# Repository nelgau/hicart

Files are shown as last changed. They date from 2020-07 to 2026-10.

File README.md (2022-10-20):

# Home Invader 64

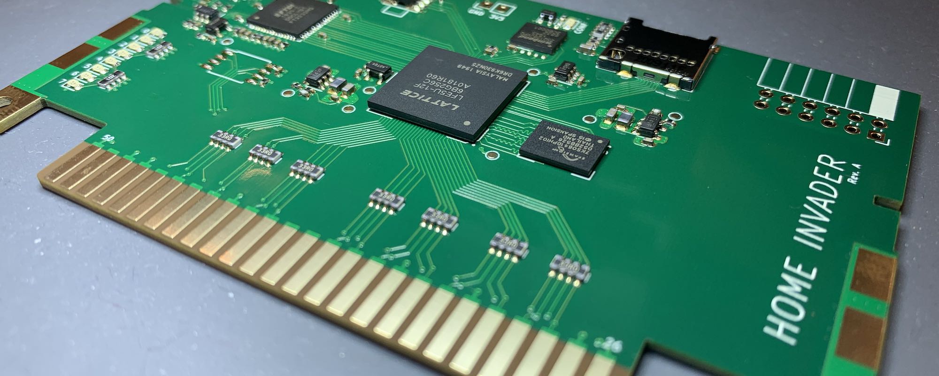
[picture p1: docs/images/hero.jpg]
Hero


This is a present for an old friend!

## Prerequisites

Get these taps:

    $ brew tap nelgau/fpga
    $ brew tap riscv-software-src/riscv

Install the following packages:

    $ brew install --HEAD yosys
    $ brew install --HEAD nelgau/fpga/nextpnr-ecp5
    $ brew install --HEAD nelgau/fpga/ecpprog
    $ brew install riscv-software-src/riscv/riscv-tools
    $ brew install icarus-verilog

Note: Building `nextpnr-ecp5` takes approximately 11 minutes on an M1 MacBook Pro.

Build a recent Python with shared object support (for cocotb) using pyenv:

    $ PYTHON_CONFIGURE_OPTS="--enable-shared" pyenv install 3.10.6

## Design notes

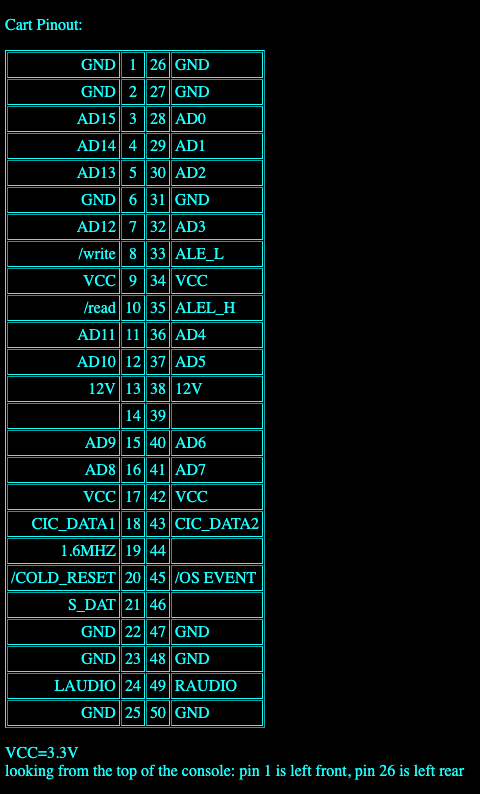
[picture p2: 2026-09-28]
docs/n64/N64 Cartridge Pinout (crazynation).png

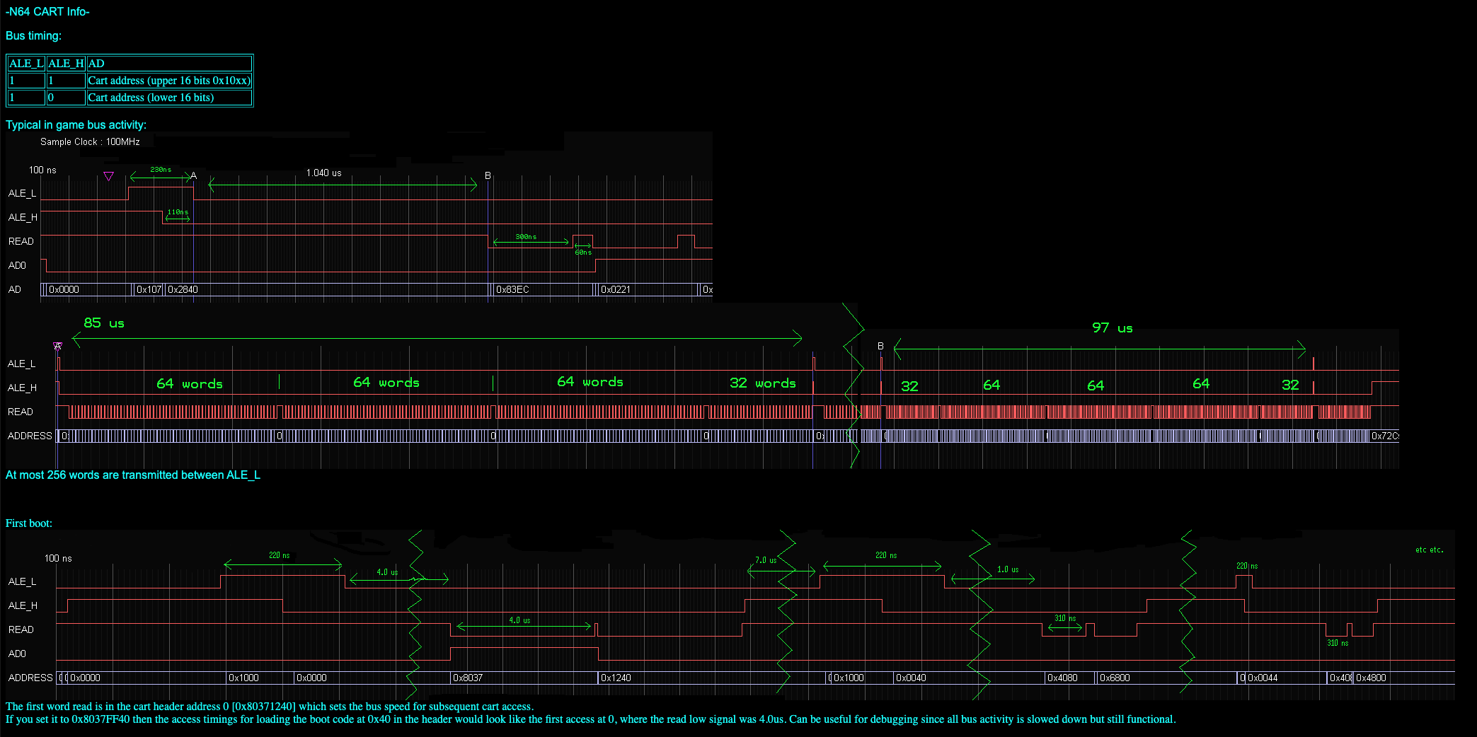
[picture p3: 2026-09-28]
docs/n64/N64 Cartridge Timings (crazynation).png

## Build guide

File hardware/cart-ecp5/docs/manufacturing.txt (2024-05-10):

**
*   JLCPCB 4-Layer Process
**

Deviations:

- Copper to hole clearance

    For BGA breakout, via hole to track
    Adjusted to 0.225mm, from 0.254mm (JLCPCB)

- Minimum text height

    For silkscreen labels throughout
    Adjusted to 0.75mm, from 1.0mm (JLCPCB)

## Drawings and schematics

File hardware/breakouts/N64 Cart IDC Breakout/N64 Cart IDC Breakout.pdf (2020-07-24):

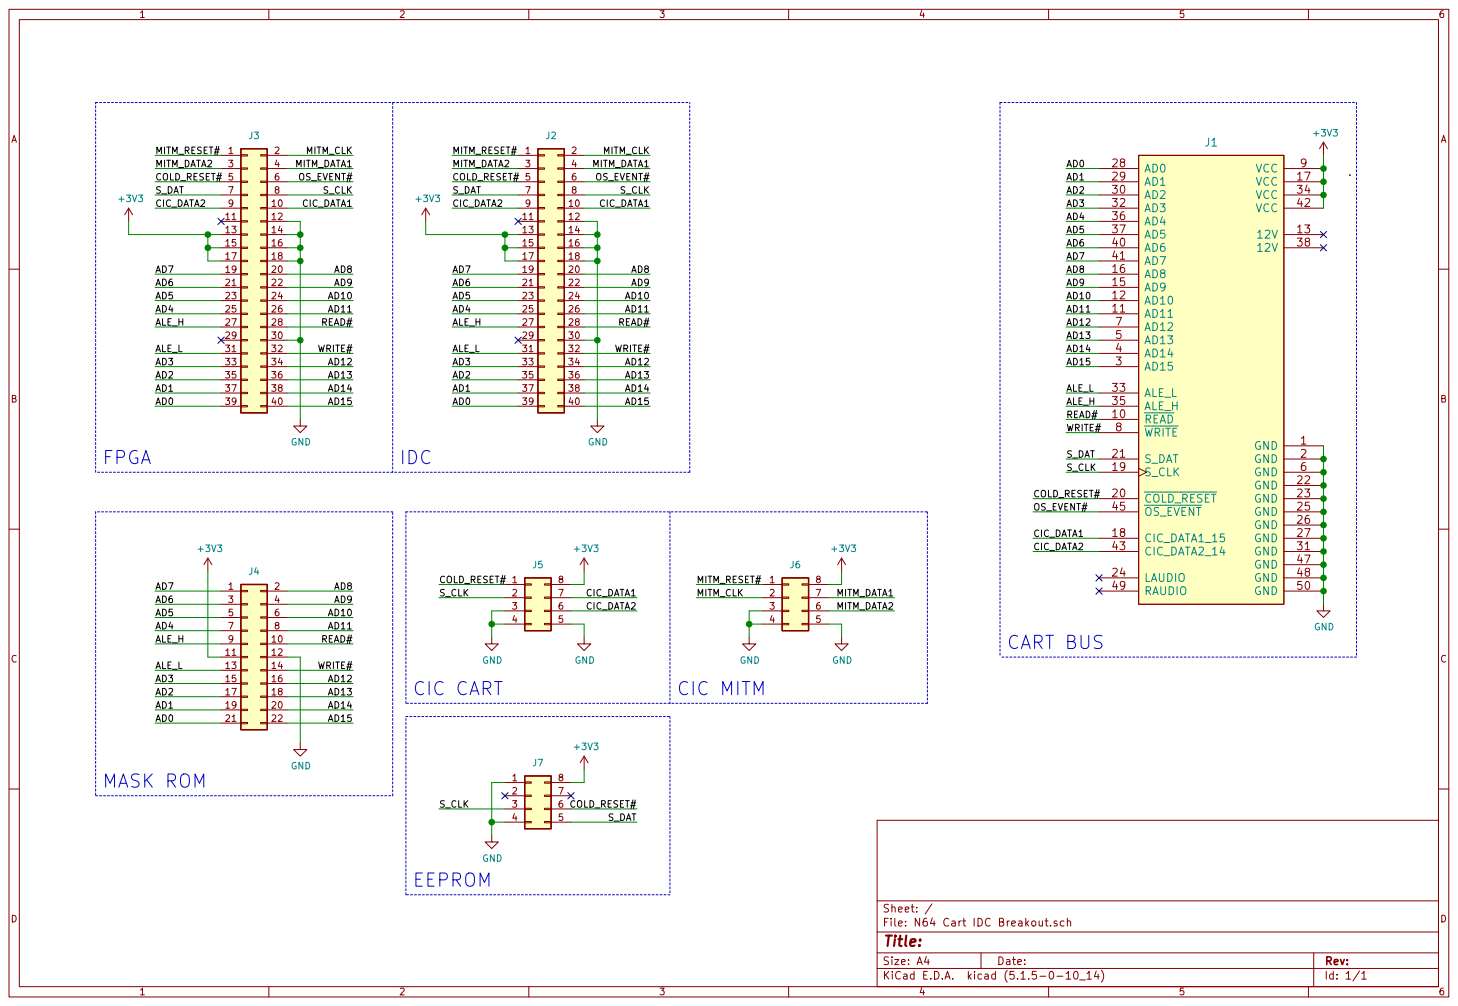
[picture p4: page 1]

Id: 1/1 Title: File: N64 Cart IDC Breakout.sch Sheet: /

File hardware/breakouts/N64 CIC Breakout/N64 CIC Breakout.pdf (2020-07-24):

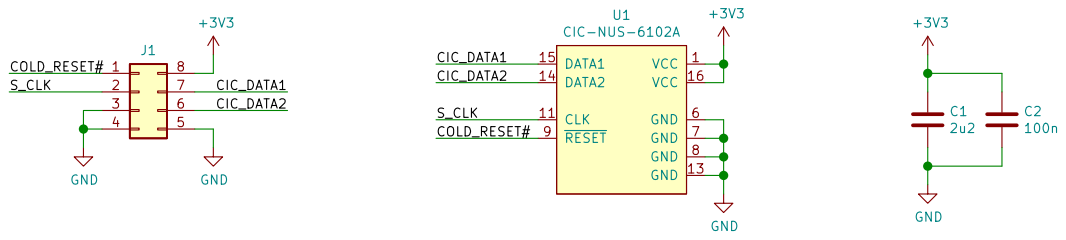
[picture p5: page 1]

Id: 1/1 Title: File: N64 CIC Breakout.sch Sheet: /

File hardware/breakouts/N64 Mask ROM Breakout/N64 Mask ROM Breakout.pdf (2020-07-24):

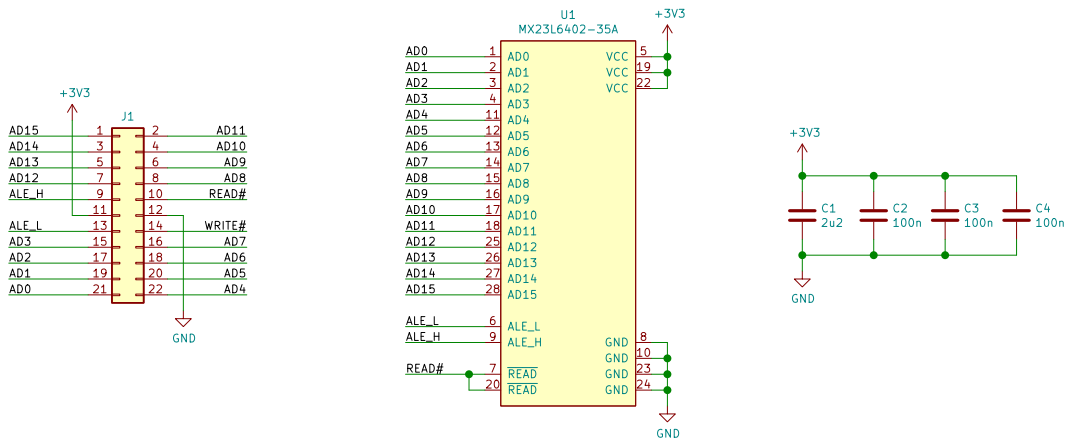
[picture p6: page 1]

Id: 1/1 Title: File: N64 Mask ROM Breakout.sch Sheet: /

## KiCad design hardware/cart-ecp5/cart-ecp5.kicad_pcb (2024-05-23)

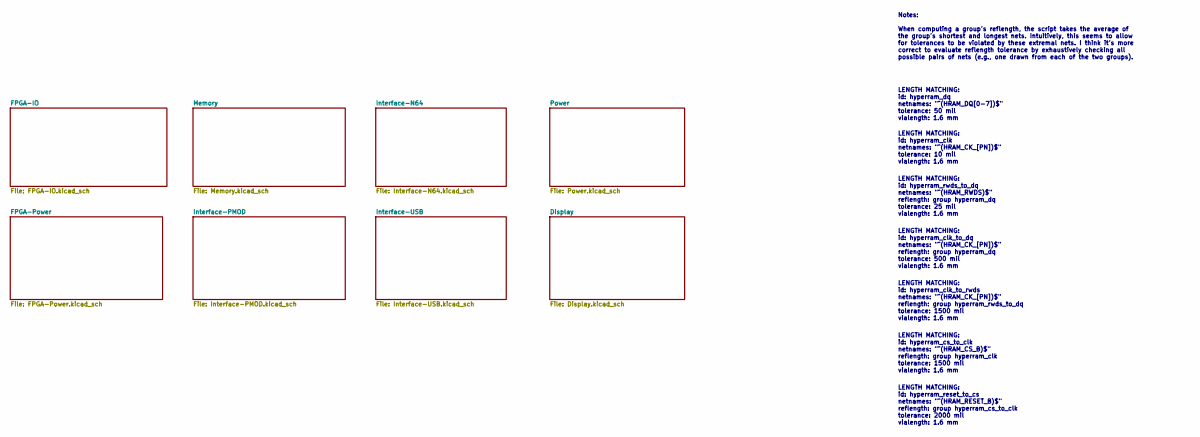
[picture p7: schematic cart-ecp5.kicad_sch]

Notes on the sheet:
LENGTH MATCHING: id: hyperram_reset_to_cs netnames: "^(HRAM_RESET_B)$" reflength: group hyperram_cs_to_clk tolerance: 2000 mil vialength: 1.6 mm
LENGTH MATCHING: id: hyperram_clk_to_dq netnames: "^(HRAM_CK_[PN])$" reflength: group hyperram_dq tolerance: 500 mil vialength: 1.6 mm
LENGTH MATCHING: id: hyperram_clk netnames: "^(HRAM_CK_[PN])$" tolerance: 10 mil vialength: 1.6 mm
LENGTH MATCHING: id: hyperram_dq netnames: "^(HRAM_DQ[0-7])$" tolerance: 50 mil vialength: 1.6 mm
LENGTH MATCHING: id: hyperram_clk_to_rwds netnames: "^(HRAM_CK_[PN])$" reflength: group hyperram_rwds_to_dq tolerance: 1500 mil vialength: 1.6 mm
LENGTH MATCHING: id: hyperram_cs_to_clk netnames: "^(HRAM_CS_B)$" reflength: group hyperram_clk tolerance: 1500 mil vialength: 1.6 mm
LENGTH MATCHING: id: hyperram_rwds_to_dq netnames: "^(HRAM_RWDS)$" reflength: group hyperram_dq tolerance: 25 mil vialength: 1.6 mm
Notes: When computing a group's reflength, the script takes the average of the group's shortest and longest nets. Intuitively, this seems to allow for tolerances to be violated by these extremal nets. I think it's more correct to evaluate reflength tolerance by exhaustively checking all possible pa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

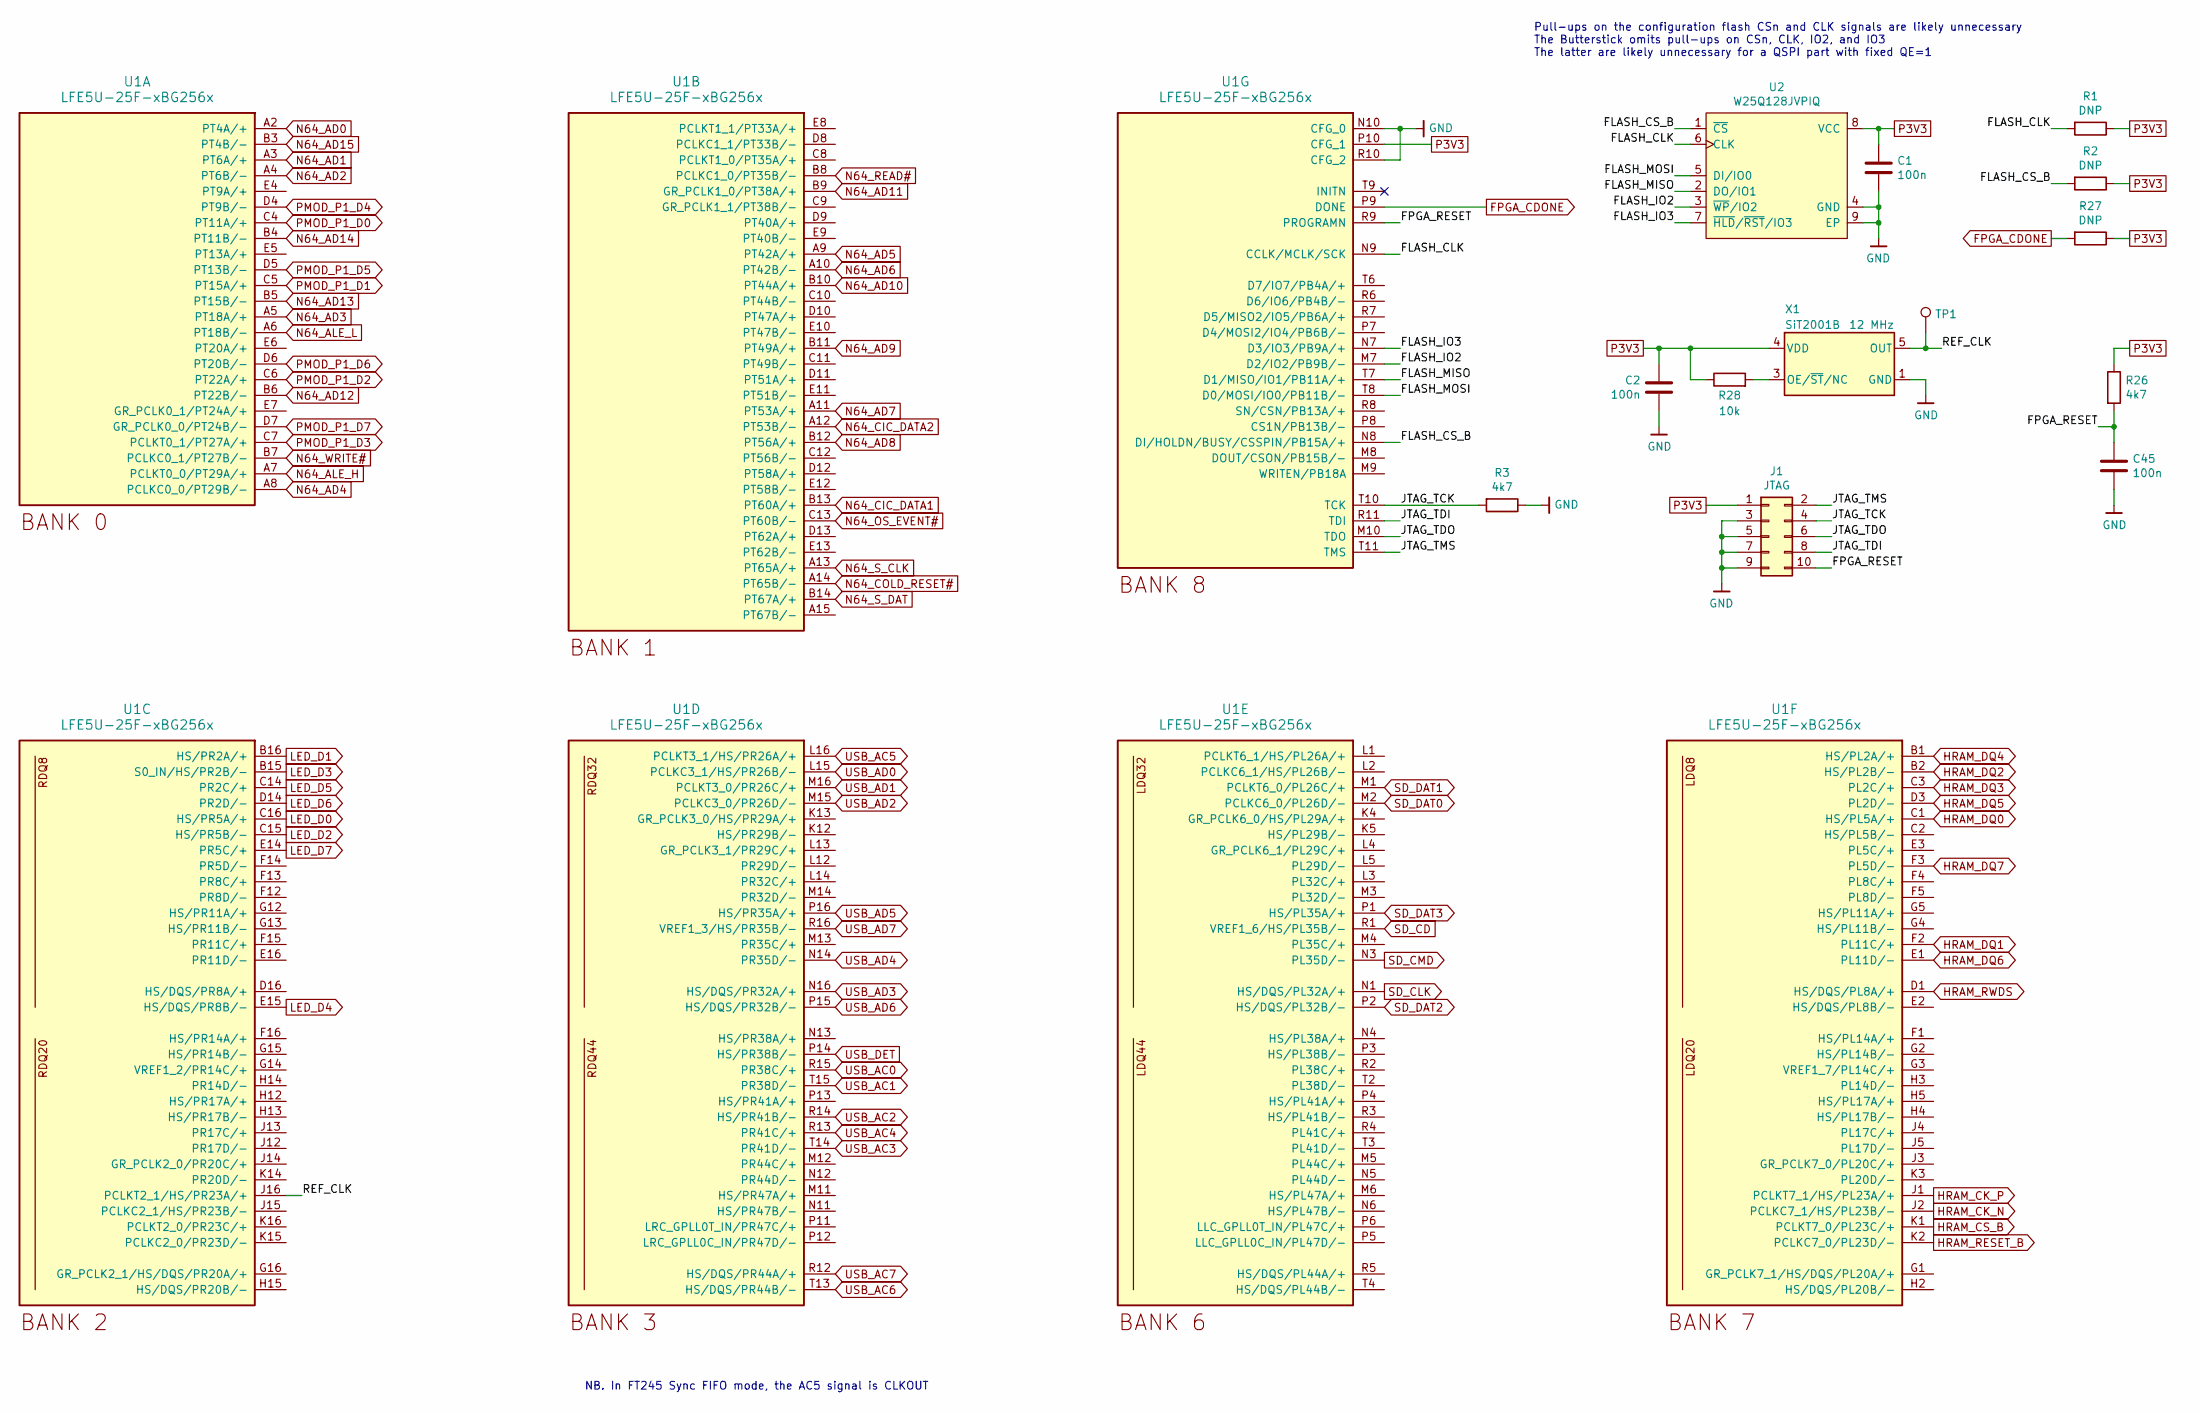
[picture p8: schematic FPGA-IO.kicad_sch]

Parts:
C1, C2, C45: 100n; C_0402_1005Metric; MPN CL05B104KO5NNNC
J1: JTAG; Samtec_FTSH-105-XX-X-DV-Mating; MPN FTSH-105-01-L-DV-K
R1, R2, R27: DNP; R_0402_1005Metric
R3, R26: 4k7; R_0402_1005Metric; MPN RC0402FR-074K7L
R28: 10k; R_0402_1005Metric; MPN RC0402FR-0710KL
TP1: TestPoint; TestPoint_Pad_D1.0mm
U1: LFE5U-25F-xBG256x; LFE5U-25F_BGA-256_14.0x14.0mm_Layout16x16_P0.8mm_Pad0.35mm; MPN LFE5U-25F-xBG256x
U2: W25Q128JVPIQ; WSON-8-1EP_6x5mm_P1.27mm_EP3.4x4mm; MPN W25Q128JVPIQ
X1: SiT2001B; SOT-23-5; MPN SiT2001BI-S2-33E-12.000000G

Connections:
/FPGA-IO/FLASH_CLK: R1.2, U1.N9 (CCLK/MCLK/SCK), U2.6 (CLK)
/FPGA-IO/FLASH_CS_B: R2.2, U1.N8 (DI/HOLDN/BUSY/CSSPIN/PB15A/+), U2.1 (~CS)
/FPGA-IO/FLASH_IO2: U1.M7 (D2/IO2/PB9B/-), U2.3 (~WP/IO2)
/FPGA-IO/FLASH_IO3: U1.N7 (D3/IO3/PB9A/+), U2.7 (~HLD/~RST/IO3)
/FPGA-IO/FLASH_MISO: U1.T7 (D1/MISO/IO1/PB11A/+), U2.2 (DO/IO1)
/FPGA-IO/FLASH_MOSI: U1.T8 (D0/MOSI/IO0/PB11B/-), U2.5 (DI/IO0)
/FPGA-IO/FPGA_RESET: C45.1, J1.10, R26.2, U1.R9 (PROGRAMN)
/FPGA-IO/JTAG_TCK: J1.4, R3.2, U1.T10 (TCK)
/FPGA-IO/JTAG_TDI: J1.8, U1.R11 (TDI)
/FPGA-IO/JTAG_TDO: J1.6, U1.M10 (TDO)
/FPGA-IO/JTAG_TMS: J1.2, U1.T11 (TMS)
/FPGA-IO/REF_CLK: TP1.1, U1.J16 (PCLKT2_1/HS/PR23A/+), X1.5 (OUT)
FPGA_CDONE: R27.2, U1.P9 (DONE); also elsewhere on the board
GND: C1.2, C2.2, C45.2, J1.3, J1.5, J1.7, J1.9, R3.1, U1.N10 (CFG_0), U1.R10 (CFG_2), U2.4 (GND), U2.9 (EP), X1.1 (GND); also elsewhere on the board
HRAM_CK_N: U1.J2 (PCLKC7_1/HS/PL23B/-); also elsewhere on the board
HRAM_CK_P: U1.J1 (PCLKT7_1/HS/PL23A/+); also elsewhere on the board
HRAM_CS_B: U1.K1 (PCLKT7_0/PL23C/+); also elsewhere on the board
HRAM_DQ0: U1.C1 (HS/PL5A/+); also elsewhere on the board
HRAM_DQ1: U1.F2 (PL11C/+); also elsewhere on the board
HRAM_DQ2: U1.B2 (HS/PL2B/-); also elsewhere on the board
HRAM_DQ3: U1.C3 (PL2C/+); also elsewhere on the board
HRAM_DQ4: U1.B1 (HS/PL2A/+); also elsewhere on the board
HRAM_DQ5: U1.D3 (PL2D/-); also elsewhere on the board
HRAM_DQ6: U1.E1 (PL11D/-); also elsewhere on the board
HRAM_DQ7: U1.F3 (PL5D/-); also elsewhere on the board
HRAM_RESET_B: U1.K2 (PCLKC7_0/PL23D/-); also elsewhere on the board
HRAM_RWDS: U1.D1 (HS/DQS/PL8A/+); also elsewhere on the board
LED_D0: U1.C16 (HS/PR5A/+); also elsewhere on the board
LED_D1: U1.B16 (HS/PR2A/+); also elsewhere on the board
LED_D2: U1.C15 (HS/PR5B/-); also elsewhere on the board
LED_D3: U1.B15 (S0_IN/HS/PR2B/-); also elsewhere on the board
LED_D4: U1.E15 (HS/DQS/PR8B/-); also elsewhere on the board
LED_D5: U1.C14 (PR2C/+); also elsewhere on the board
LED_D6: U1.D14 (PR2D/-); also elsewhere on the board
LED_D7: U1.E14 (PR5C/+); also elsewhere on the board
N64_AD0: U1.A2 (PT4A/+); also elsewhere on the board
N64_AD1: U1.A3 (PT6A/+); also elsewhere on the board
N64_AD2: U1.A4 (PT6B/-); also elsewhere on the board
N64_AD3: U1.A5 (PT18A/+); also elsewhere on the board
N64_AD4: U1.A8 (PCLKC0_0/PT29B/-); also elsewhere on the board
N64_AD5: U1.A9 (PT42A/+); also elsewhere on the board
N64_AD6: U1.A10 (PT42B/-); also elsewhere on the board
N64_AD7: U1.A11 (PT53A/+); also elsewhere on the board
N64_AD8: U1.B12 (PT56A/+); also elsewhere on the board
N64_AD9: U1.B11 (PT49A/+); also elsewhere on the board
N64_AD10: U1.B10 (PT44A/+); also elsewhere on the board
N64_AD11: U1.B9 (GR_PCLK1_0/PT38A/+); also elsewhere on the board
N64_AD12: U1.B6 (PT22B/-); also elsewhere on the board
N64_AD13: U1.B5 (PT15B/-); also elsewhere on the board
N64_AD14: U1.B4 (PT11B/-); also elsewhere on the board
N64_AD15: U1.B3 (PT4B/-); also elsewhere on the board
N64_ALE_H: U1.A7 (PCLKT0_0/PT29A/+); also elsewhere on the board
N64_ALE_L: U1.A6 (PT18B/-); also elsewhere on the board
N64_CIC_DATA1: U1.B13 (PT60A/+); also elsewhere on the board
N64_CIC_DATA2: U1.A12 (PT53B/-); also elsewhere on the board
N64_COLD_RESET#: U1.A14 (PT65B/-); also elsewhere on the board
N64_OS_EVENT#: U1.C13 (PT60B/-); also elsewhere on the board
N64_READ#: U1.B8 (PCLKC1_0/PT35B/-); also elsewhere on the board
N64_S_CLK: U1.A13 (PT65A/+); also elsewhere on the board
N64_S_DAT: U1.B14 (PT67A/+); also elsewhere on the board
N64_WRITE#: U1.B7 (PCLKC0_1/PT27B/-); also elsewhere on the board
unnamed: R28.2, X1.3 (OE/~ST/NC)
P3V3: C1.1, C2.1, J1.1, R1.1, R2.1, R26.1, R27.1, R28.1, U1.P10 (CFG_1), U2.8 (VCC), X1.4 (VDD); also elsewhere on the board
PMOD_P1_D0: U1.C4 (PT11A/+); also elsewhere on the board
PMOD_P1_D1: U1.C5 (PT15A/+); also elsewhere on the board
PMOD_P1_D2: U1.C6 (PT22A/+); also elsewhere on the board
PMOD_P1_D3: U1.C7 (PCLKT0_1/PT27A/+); also elsewhere on the board
PMOD_P1_D4: U1.D4 (PT9B/-); also elsewhere on the board
PMOD_P1_D5: U1.D5 (PT13B/-); also elsewhere on the board
PMOD_P1_D6: U1.D6 (PT20B/-); also elsewhere on the board
PMOD_P1_D7: U1.D7 (GR_PCLK0_0/PT24B/-); also elsewhere on the board
SD_CD: U1.R1 (VREF1_6/HS/PL35B/-); also elsewhere on the board
SD_CLK: U1.N1 (HS/DQS/PL32A/+); also elsewhere on the board
SD_CMD: U1.N3 (PL35D/-); also elsewhere on the board
SD_DAT0: U1.M2 (PCLKC6_0/PL26D/-); also elsewhere on the board
SD_DAT1: U1.M1 (PCLKT6_0/PL26C/+); also elsewhere on the board
SD_DAT2: U1.P2 (HS/DQS/PL32B/-); also elsewhere on the board
SD_DAT3: U1.P1 (HS/PL35A/+); also elsewhere on the board
USB_AC0: U1.R15 (PR38C/+); also elsewhere on the board
USB_AC1: U1.T15 (PR38D/-); also elsewhere on the board
USB_AC2: U1.R14 (HS/PR41B/-); also elsewhere on the board
USB_AC3: U1.T14 (PR41D/-); also elsewhere on the board
USB_AC4: U1.R13 (PR41C/+); also elsewhere on the board
USB_AC5: U1.L16 (PCLKT3_1/HS/PR26A/+); also elsewhere on the board
USB_AC6: U1.T13 (HS/DQS/PR44B/-); also elsewhere on the board
USB_AC7: U1.R12 (HS/DQS/PR44A/+); also elsewhere on the board
USB_AD0: U1.L15 (PCLKC3_1/HS/PR26B/-); also elsewhere on the board
USB_AD1: U1.M16 (PCLKT3_0/PR26C/+); also elsewhere on the board
USB_AD2: U1.M15 (PCLKC3_0/PR26D/-); also elsewhere on the board
USB_AD3: U1.N16 (HS/DQS/PR32A/+); also elsewhere on the board
USB_AD4: U1.N14 (PR35D/-); also elsewhere on the board
USB_AD5: U1.P16 (HS/PR35A/+); also elsewhere on the board
USB_AD6: U1.P15 (HS/DQS/PR32B/-); also elsewhere on the board
USB_AD7: U1.R16 (VREF1_3/HS/PR35B/-); also elsewhere on the board
USB_DET: U1.P14 (HS/PR38B/-); also elsewhere on the board

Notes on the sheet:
NB. In FT245 Sync FIFO mode, the AC5 signal is CLKOUT
Pull-ups on the configuration flash CSn and CLK signals are likely unnecessary The Butterstick omits pull-ups on CSn, CLK, IO2, and IO3 The latter are likely unnecessary for a QSPI part with fixed QE=1

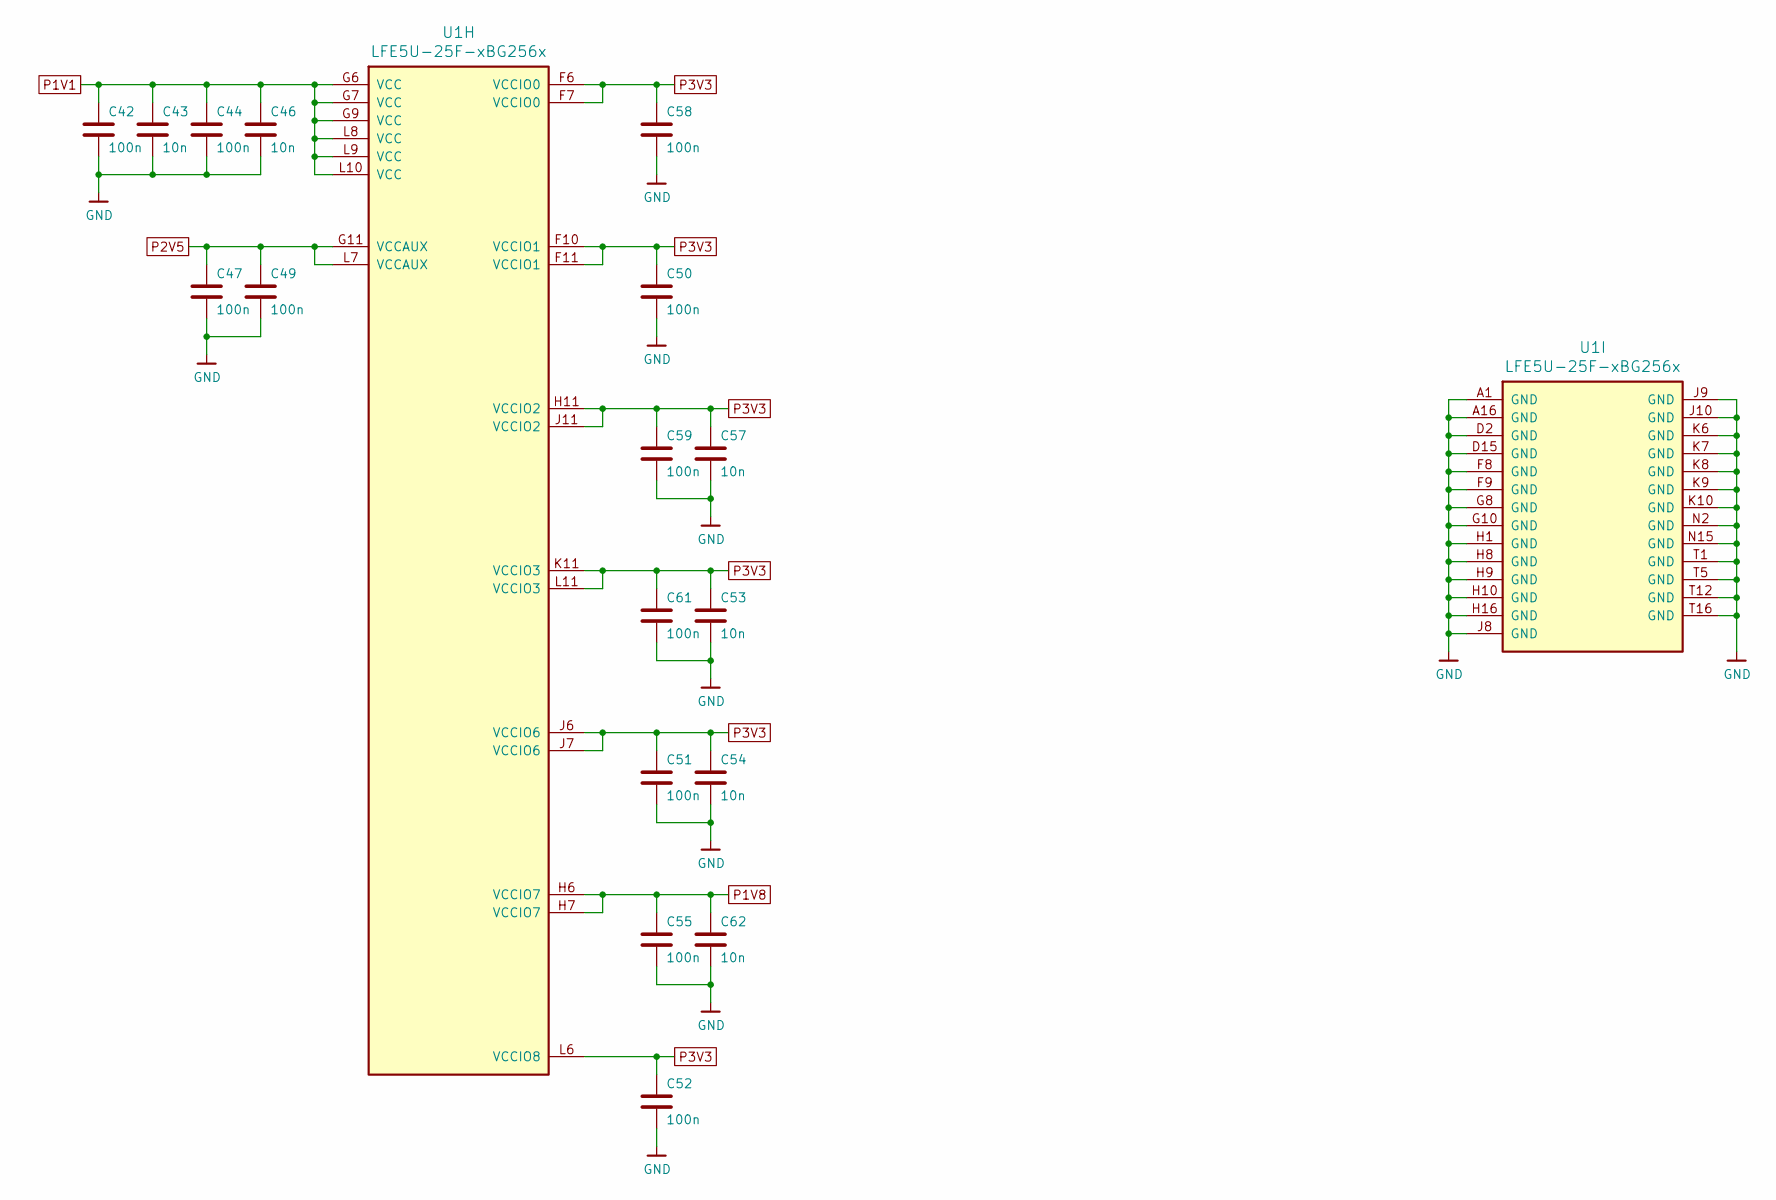
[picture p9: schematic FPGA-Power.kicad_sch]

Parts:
C42, C44, C47, C49, C50, C51, C52, C55, C58, C59, C61: 100n; C_0402_1005Metric; MPN CL05B104KO5NNNC
C43, C46, C53, C54, C57, C62: 10n; C_0402_1005Metric; MPN CL05B103KB5NNNC
U1: LFE5U-25F-xBG256x; LFE5U-25F_BGA-256_14.0x14.0mm_Layout16x16_P0.8mm_Pad0.35mm; MPN LFE5U-25F-xBG256x

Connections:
GND: C42.2, C43.2, C44.2, C46.2, C47.2, C49.2, C50.2, C51.2, C52.2, C53.2, C54.2, C55.2, C57.2, C58.2, C59.2, C61.2, C62.2, U1.A1 (GND), U1.A16 (GND), U1.D2 (GND), U1.D15 (GND), U1.F8 (GND), U1.F9 (GND), U1.G8 (GND), U1.G10 (GND), U1.H1 (GND), U1.H8 (GND), U1.H9 (GND), U1.H10 (GND), U1.H16 (GND), U1.J8 (GND), U1.J9 (GND), U1.J10 (GND), U1.K6 (GND), U1.K7 (GND), U1.K8 (GND), U1.K9 (GND), U1.K10 (GND), U1.N2 (GND), U1.N15 (GND), U1.T1 (GND), U1.T5 (GND), U1.T12 (GND), U1.T16 (GND); also elsewhere on the board
P1V1: C42.1, C43.1, C44.1, C46.1, U1.G6 (VCC), U1.G7 (VCC), U1.G9 (VCC), U1.L8 (VCC), U1.L9 (VCC), U1.L10 (VCC); also elsewhere on the board
P1V8: C55.1, C62.1, U1.H6 (VCCIO7), U1.H7 (VCCIO7); also elsewhere on the board
P2V5: C47.1, C49.1, U1.G11 (VCCAUX), U1.L7 (VCCAUX); also elsewhere on the board
P3V3: C50.1, C51.1, C52.1, C53.1, C54.1, C57.1, C58.1, C59.1, C61.1, U1.F6 (VCCIO0), U1.F7 (VCCIO0), U1.F10 (VCCIO1), U1.F11 (VCCIO1), U1.H11 (VCCIO2), U1.J6 (VCCIO6), U1.J7 (VCCIO6), U1.J11 (VCCIO2), U1.K11 (VCCIO3), U1.L6 (VCCIO8), U1.L11 (VCCIO3); also elsewhere on the board

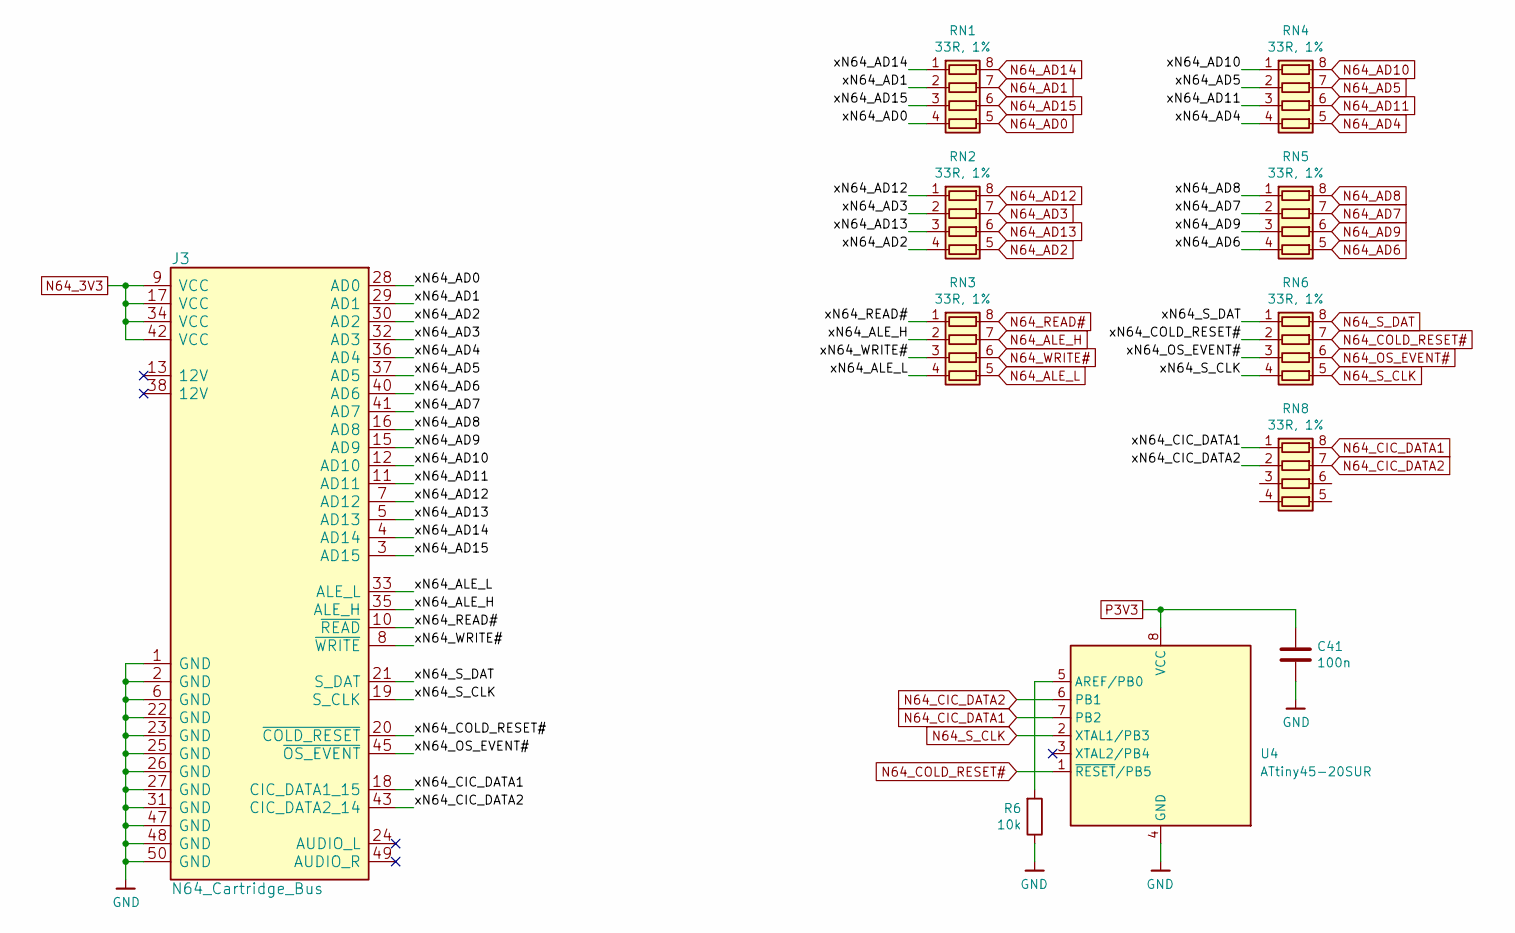
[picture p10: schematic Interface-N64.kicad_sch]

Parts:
C41: 100n; C_0402_1005Metric; MPN CL05B104KO5NNNC
J3: N64_Cartridge_Bus; N64_Cartridge_Edge
R6: 10k; R_0402_1005Metric; MPN RC0402FR-0710KL
RN1, RN2, RN3, RN4, RN5, RN6, RN8: 33R, 1%; R_Array_Convex_4x0603; MPN YC164-FR-0733RL
U4: ATtiny45-20SUR; SOIC-8W_5.3x5.3mm_P1.27mm; MPN ATTINY45-20SUR

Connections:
/Interface-N64/xN64_AD0: J3.28 (AD0), RN1.4 (R4.1)
/Interface-N64/xN64_AD1: J3.29 (AD1), RN1.2 (R2.1)
/Interface-N64/xN64_AD2: J3.30 (AD2), RN2.4 (R4.1)
/Interface-N64/xN64_AD3: J3.32 (AD3), RN2.2 (R2.1)
/Interface-N64/xN64_AD4: J3.36 (AD4), RN4.4 (R4.1)
/Interface-N64/xN64_AD5: J3.37 (AD5), RN4.2 (R2.1)
/Interface-N64/xN64_AD6: J3.40 (AD6), RN5.4 (R4.1)
/Interface-N64/xN64_AD7: J3.41 (AD7), RN5.2 (R2.1)
/Interface-N64/xN64_AD8: J3.16 (AD8), RN5.1 (R1.1)
/Interface-N64/xN64_AD9: J3.15 (AD9), RN5.3 (R3.1)
/Interface-N64/xN64_AD10: J3.12 (AD10), RN4.1 (R1.1)
/Interface-N64/xN64_AD11: J3.11 (AD11), RN4.3 (R3.1)
/Interface-N64/xN64_AD12: J3.7 (AD12), RN2.1 (R1.1)
/Interface-N64/xN64_AD13: J3.5 (AD13), RN2.3 (R3.1)
/Interface-N64/xN64_AD14: J3.4 (AD14), RN1.1 (R1.1)
/Interface-N64/xN64_AD15: J3.3 (AD15), RN1.3 (R3.1)
/Interface-N64/xN64_ALE_H: J3.35 (ALE_H), RN3.2 (R2.1)
/Interface-N64/xN64_ALE_L: J3.33 (ALE_L), RN3.4 (R4.1)
/Interface-N64/xN64_CIC_DATA1: J3.18 (CIC_DATA1_15), RN8.1 (R1.1)
/Interface-N64/xN64_CIC_DATA2: J3.43 (CIC_DATA2_14), RN8.2 (R2.1)
/Interface-N64/xN64_COLD_RESET#: J3.20 (~COLD_RESET), RN6.2 (R2.1)
/Interface-N64/xN64_OS_EVENT#: J3.45 (~OS_EVENT), RN6.3 (R3.1)
/Interface-N64/xN64_READ#: J3.10 (~READ), RN3.1 (R1.1)
/Interface-N64/xN64_S_CLK: J3.19 (S_CLK), RN6.4 (R4.1)
/Interface-N64/xN64_S_DAT: J3.21 (S_DAT), RN6.1 (R1.1)
/Interface-N64/xN64_WRITE#: J3.8 (~WRITE), RN3.3 (R3.1)
GND: C41.2, J3.1 (GND), J3.2 (GND), J3.6 (GND), J3.22 (GND), J3.23 (GND), J3.25 (GND), J3.26 (GND), J3.27 (GND), J3.31 (GND), J3.47 (GND), J3.48 (GND), J3.50 (GND), R6.1, U4.4 (GND); also elsewhere on the board
N64_3V3: J3.9 (VCC), J3.17 (VCC), J3.34 (VCC), J3.42 (VCC); also elsewhere on the board
N64_AD0: RN1.5 (R4.2); also elsewhere on the board
N64_AD1: RN1.7 (R2.2); also elsewhere on the board
N64_AD2: RN2.5 (R4.2); also elsewhere on the board
N64_AD3: RN2.7 (R2.2); also elsewhere on the board
N64_AD4: RN4.5 (R4.2); also elsewhere on the board
N64_AD5: RN4.7 (R2.2); also elsewhere on the board
N64_AD6: RN5.5 (R4.2); also elsewhere on the board
N64_AD7: RN5.7 (R2.2); also elsewhere on the board
N64_AD8: RN5.8 (R1.2); also elsewhere on the board
N64_AD9: RN5.6 (R3.2); also elsewhere on the board
N64_AD10: RN4.8 (R1.2); also elsewhere on the board
N64_AD11: RN4.6 (R3.2); also elsewhere on the board
N64_AD12: RN2.8 (R1.2); also elsewhere on the board
N64_AD13: RN2.6 (R3.2); also elsewhere on the board
N64_AD14: RN1.8 (R1.2); also elsewhere on the board
N64_AD15: RN1.6 (R3.2); also elsewhere on the board
N64_ALE_H: RN3.7 (R2.2); also elsewhere on the board
N64_ALE_L: RN3.5 (R4.2); also elsewhere on the board
N64_CIC_DATA1: RN8.8 (R1.2), U4.7 (PB2); also elsewhere on the board
N64_CIC_DATA2: RN8.7 (R2.2), U4.6 (PB1); also elsewhere on the board
N64_COLD_RESET#: RN6.7 (R2.2), U4.1 (~RESET/PB5); also elsewhere on the board
N64_OS_EVENT#: RN6.6 (R3.2); also elsewhere on the board
N64_READ#: RN3.8 (R1.2); also elsewhere on the board
N64_S_CLK: RN6.5 (R4.2), U4.2 (XTAL1/PB3); also elsewhere on the board
N64_S_DAT: RN6.8 (R1.2); also elsewhere on the board
N64_WRITE#: RN3.6 (R3.2); also elsewhere on the board
unnamed: R6.2, U4.5 (AREF/PB0)
P3V3: C41.1, U4.8 (VCC); also elsewhere on the board

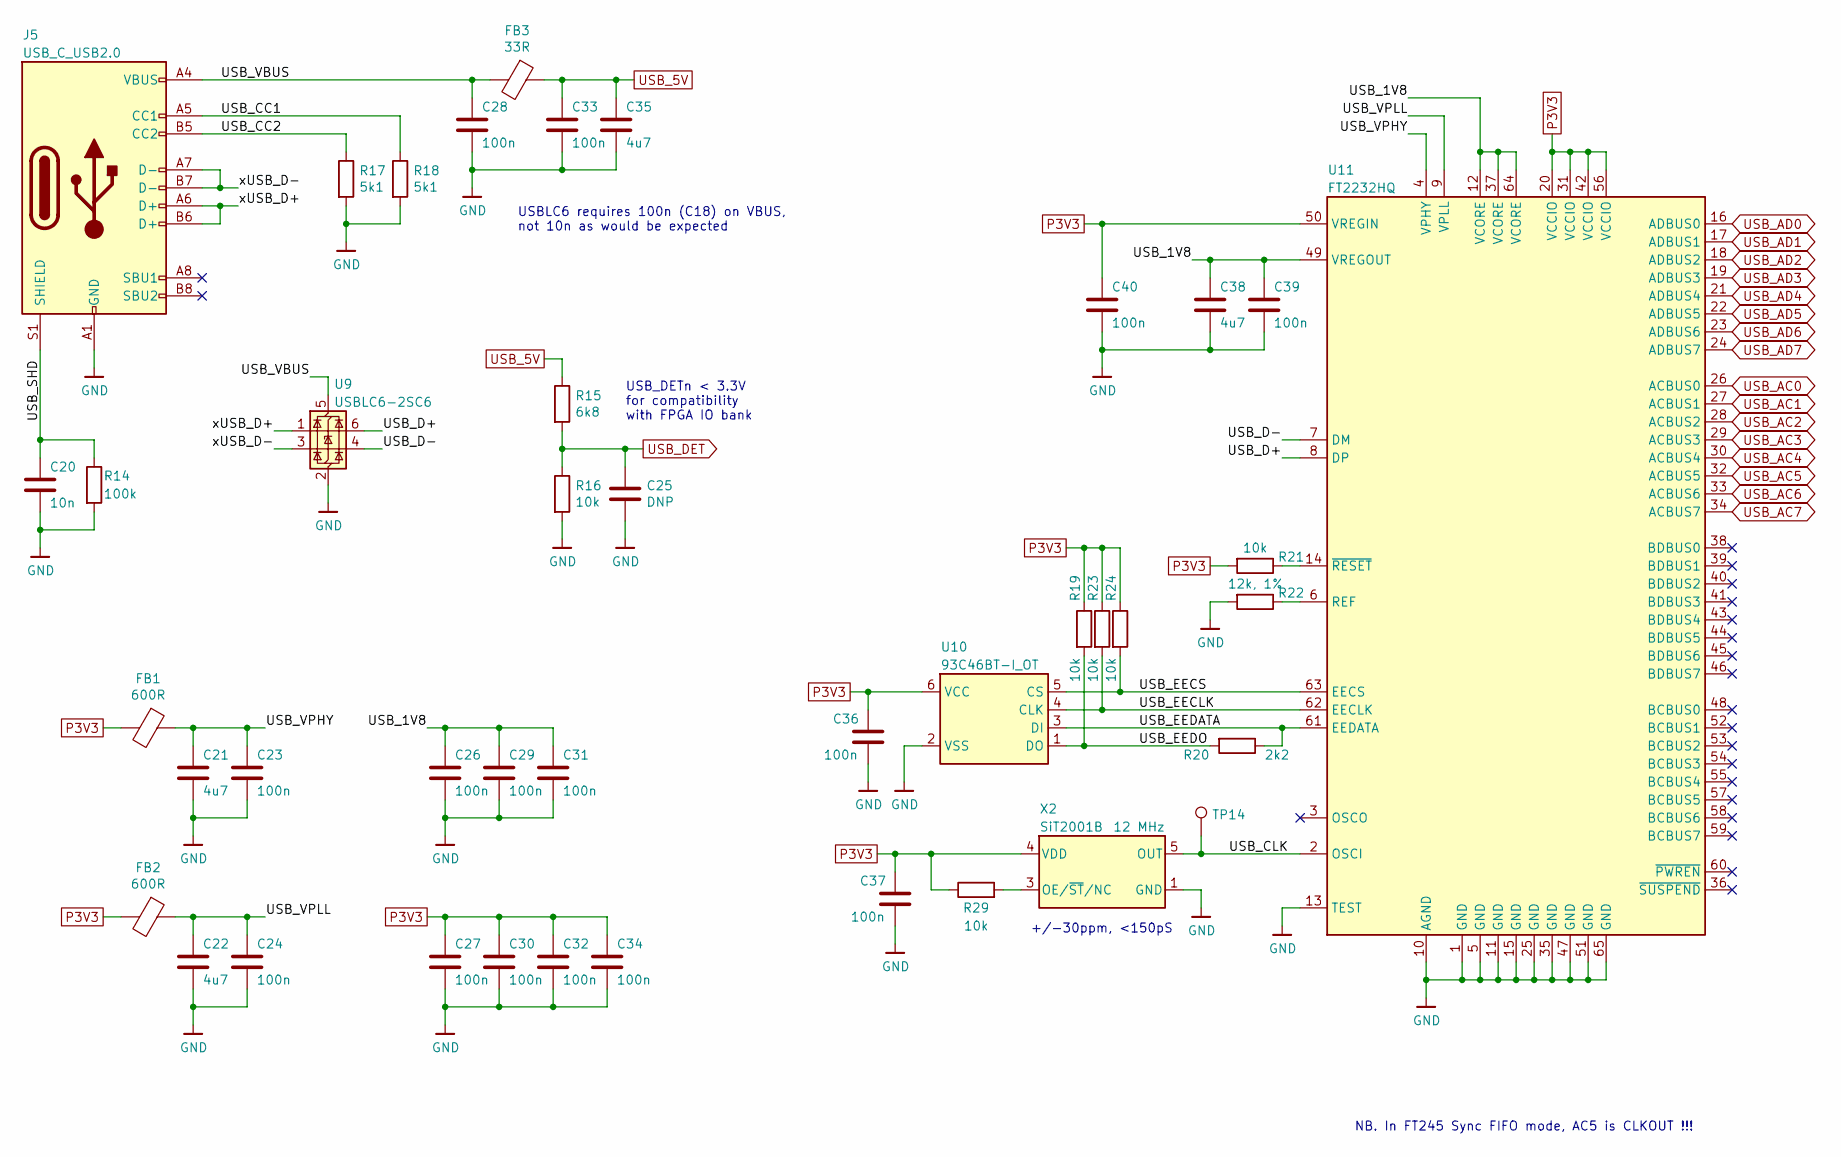
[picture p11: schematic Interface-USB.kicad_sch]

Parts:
C20: 10n; C_0402_1005Metric; MPN CL05B103KB5NNNC
C21, C22, C35, C38: 4u7; C_0402_1005Metric; MPN CL05A475KP5NRNC
C23, C24, C26, C27, C28, C29, C30, C31, C32, C33, C34, C36, C37, C39, C40: 100n; C_0402_1005Metric; MPN CL05B104KO5NNNC
C25: DNP; C_0402_1005Metric
FB1, FB2: 600R; L_0402_1005Metric; MPN BLM15PX601SN1D
FB3: 33R; L_0402_1005Metric; MPN MPZ1005S330HT000
J5: USB_C_USB2.0; USB_C_Receptacle_HRO_TYPE-C-31-M-12; MPN TYPE-C-31-M-12
R14: 100k; R_0402_1005Metric; MPN RC0402FR-07100KL
R15: 6k8; R_0402_1005Metric; MPN RC0402FR-076K8L
R16, R19, R21, R23, R24, R29: 10k; R_0402_1005Metric; MPN RC0402FR-0710KL
R17, R18: 5k1; R_0402_1005Metric; MPN RC0402FR-075K1L
R20: 2k2; R_0402_1005Metric; MPN RC0402FR-072K2L
R22: 12k, 1%; R_0402_1005Metric; MPN RC0402FR-0712KL
TP14: TestPoint; TestPoint_Pad_D1.0mm
U9: USBLC6-2SC6; SOT-23-6; MPN USBLC6-2SC6
U10: 93C46BT-I_OT; SOT-23-6; MPN 93C46BT-I/OT
U11: FT2232HQ; QFN-64-1EP_9x9mm_P0.5mm_EP4.35x4.35mm; MPN FT2232HQ
X2: SiT2001B; SOT-23-5; MPN SiT2001BI-S2-33E-12.000000G

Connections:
/Interface-USB/USB_1V8: C26.1, C29.1, C31.1, C38.1, C39.1, U11.12 (VCORE), U11.37 (VCORE), U11.49 (VREGOUT), U11.64 (VCORE)
/Interface-USB/USB_CC1: J5.A5 (CC1), R18.1
/Interface-USB/USB_CC2: J5.B5 (CC2), R17.1
/Interface-USB/USB_CLK: TP14.1, U11.2 (OSCI), X2.5 (OUT)
/Interface-USB/USB_D+: U9.6 (I/O1), U11.8 (DP)
/Interface-USB/USB_D-: U9.4 (I/O2), U11.7 (DM)
/Interface-USB/USB_EECLK: R23.2, U10.4 (CLK), U11.62 (EECLK)
/Interface-USB/USB_EECS: R24.2, U10.5 (CS), U11.63 (EECS)
/Interface-USB/USB_EEDATA: R20.1, U10.3 (DI), U11.61 (EEDATA)
/Interface-USB/USB_EEDO: R19.2, R20.2, U10.1 (DO)
/Interface-USB/USB_SHD: C20.1, J5.S1 (SHIELD), R14.1
/Interface-USB/USB_VBUS: C28.1, FB3.2, J5.A4 (VBUS), J5.A9 (VBUS), J5.B4 (VBUS), J5.B9 (VBUS), U9.5 (VBUS)
/Interface-USB/USB_VPHY: C21.1, C23.1, FB1.1, U11.4 (VPHY)
/Interface-USB/USB_VPLL: C22.1, C24.1, FB2.1, U11.9 (VPLL)
/Interface-USB/xUSB_D+: J5.A6 (D+), J5.B6 (D+), U9.1 (I/O1)
/Interface-USB/xUSB_D-: J5.A7 (D-), J5.B7 (D-), U9.3 (I/O2)
GND: C20.2, C21.2, C22.2, C23.2, C24.2, C25.2, C26.2, C27.2, C28.2, C29.2, C30.2, C31.2, C32.2, C33.2, C34.2, C35.2, C36.2, C37.2, C38.2, C39.2, C40.2, J5.A1 (GND), J5.A12 (GND), J5.B1 (GND), J5.B12 (GND), R14.2, R16.2, R17.2, R18.2, R22.2, U9.2 (GND), U10.2 (VSS), U11.1 (GND), U11.5 (GND), U11.10 (AGND), U11.11 (GND), U11.13 (TEST), U11.15 (GND), U11.25 (GND), U11.35 (GND), U11.47 (GND), U11.51 (GND), U11.65 (GND), X2.1 (GND); also elsewhere on the board
unnamed: R22.1, U11.6 (REF)
unnamed: R21.1, U11.14 (~RESET)
unnamed: R29.2, X2.3 (OE/~ST/NC)
P3V3: C27.1, C30.1, C32.1, C34.1, C36.1, C37.1, C40.1, FB1.2, FB2.2, R19.1, R21.2, R23.1, R24.1, R29.1, U10.6 (VCC), U11.20 (VCCIO), U11.31 (VCCIO), U11.42 (VCCIO), U11.50 (VREGIN), U11.56 (VCCIO), X2.4 (VDD); also elsewhere on the board
USB_5V: C33.1, C35.1, FB3.1, R15.1; also elsewhere on the board
USB_AC0: U11.26 (ACBUS0); also elsewhere on the board
USB_AC1: U11.27 (ACBUS1); also elsewhere on the board
USB_AC2: U11.28 (ACBUS2); also elsewhere on the board
USB_AC3: U11.29 (ACBUS3); also elsewhere on the board
USB_AC4: U11.30 (ACBUS4); also elsewhere on the board
USB_AC5: U11.32 (ACBUS5); also elsewhere on the board
USB_AC6: U11.33 (ACBUS6); also elsewhere on the board
USB_AC7: U11.34 (ACBUS7); also elsewhere on the board
USB_AD0: U11.16 (ADBUS0); also elsewhere on the board
USB_AD1: U11.17 (ADBUS1); also elsewhere on the board
USB_AD2: U11.18 (ADBUS2); also elsewhere on the board
USB_AD3: U11.19 (ADBUS3); also elsewhere on the board
USB_AD4: U11.21 (ADBUS4); also elsewhere on the board
USB_AD5: U11.22 (ADBUS5); also elsewhere on the board
USB_AD6: U11.23 (ADBUS6); also elsewhere on the board
USB_AD7: U11.24 (ADBUS7); also elsewhere on the board
USB_DET: C25.1, R15.2, R16.1; also elsewhere on the board

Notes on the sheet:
USB_DETn < 3.3V for compatibility with FPGA IO bank
USBLC6 requires 100n (C18) on VBUS, not 10n as would be expected
+/-30ppm, <150pS
NB. In FT245 Sync FIFO mode, AC5 is CLKOUT !!!

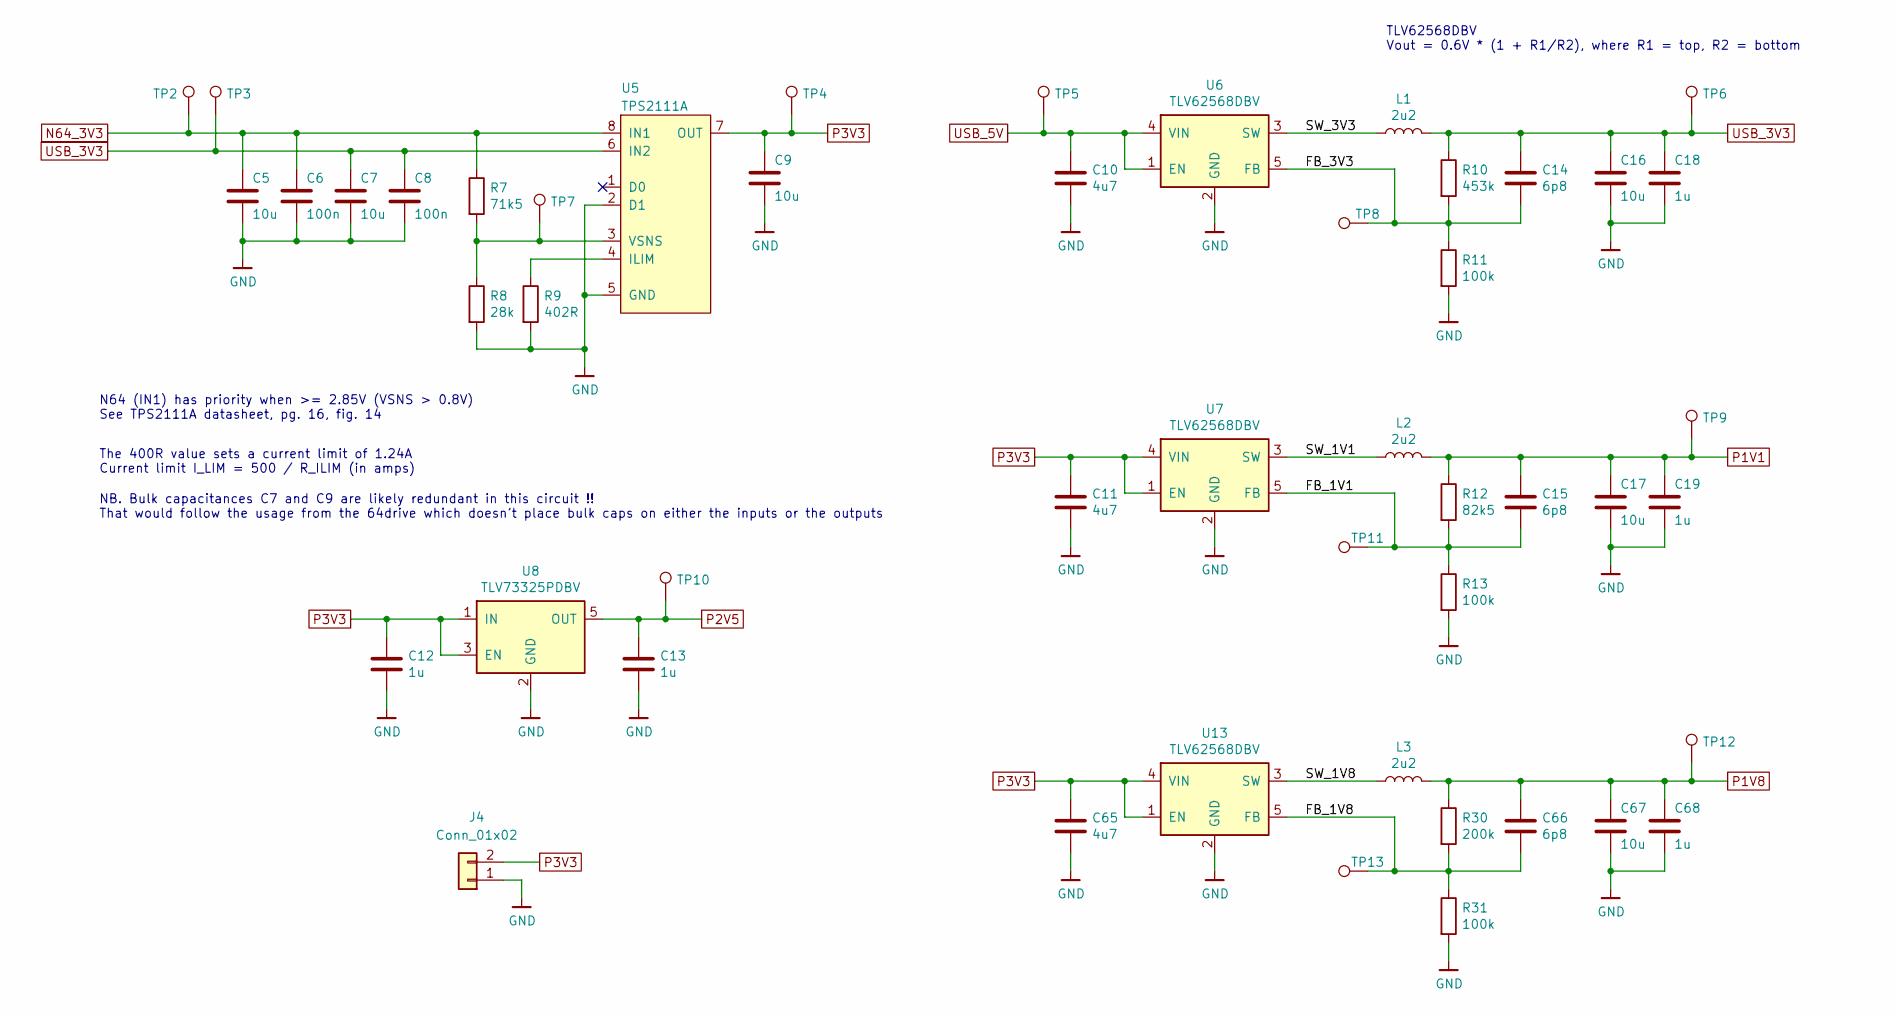
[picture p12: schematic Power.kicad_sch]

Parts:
C5, C7, C9, C16, C17, C67: 10u; C_0603_1608Metric; MPN CL10A106MQ8NNND
C6, C8: 100n; C_0402_1005Metric; MPN CL05B104KO5NNNC
C10, C11, C65: 4u7; C_0402_1005Metric; MPN CL05A475KP5NRNC
C12, C13, C18, C19, C68: 1u; C_0402_1005Metric; MPN CL05A105KO5NNNC
C14, C15, C66: 6p8; C_0402_1005Metric; MPN CC0402CRNPO9BN6R8
J4: Conn_01x02; PinHeader_1x02_P2.54mm_Vertical; MPN 22284020
L1, L2, L3: 2u2; L_0805_2012Metric; MPN LQM21PN2R2NGCD
R7: 71k5; R_0402_1005Metric; MPN RC0402FR-0771K5L
R8: 28k; R_0402_1005Metric; MPN RC0402FR-0728KL
R9: 402R; R_0402_1005Metric; MPN RC0402FR-07402RL
R10: 453k; R_0402_1005Metric; MPN RC0402FR-07453KL
R11, R13, R31: 100k; R_0402_1005Metric; MPN RC0402FR-07100KL
R12: 82k5; R_0402_1005Metric; MPN RC0402FR-0782K5L
R30: 200k; R_0402_1005Metric; MPN RC0402FR-07200KL
TP2, TP3, TP4, TP5, TP6, TP7, TP8, TP9, TP10, TP11, TP12, TP13: TestPoint; TestPoint_Pad_D1.0mm
U5: TPS2111A; TSSOP-8_4.4x3mm_P0.65mm; MPN TPS2111APWR
U6, U7, U13: TLV62568DBV; SOT-23-5; MPN TLV62568DBVR
U8: TLV73325PDBV; SOT-23-5; MPN TLV73325PDBVR

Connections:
/Power/FB_1V1: C15.2, R12.2, R13.1, TP11.1, U7.5 (FB)
/Power/FB_1V8: C66.2, R30.2, R31.1, TP13.1, U13.5 (FB)
/Power/FB_3V3: C14.2, R10.2, R11.1, TP8.1, U6.5 (FB)
/Power/SW_1V1: L2.1, U7.3 (SW)
/Power/SW_1V8: L3.1, U13.3 (SW)
/Power/SW_3V3: L1.1, U6.3 (SW)
GND: C5.2, C6.2, C7.2, C8.2, C9.2, C10.2, C11.2, C12.2, C13.2, C16.2, C17.2, C18.2, C19.2, C65.2, C67.2, C68.2, J4.1, R8.2, R9.2, R11.2, R13.2, R31.2, U5.2 (D1), U5.5 (GND), U6.2 (GND), U7.2 (GND), U8.2 (GND), U13.2 (GND); also elsewhere on the board
N64_3V3: C5.1, C6.1, R7.1, TP2.1, U5.8 (IN1); also elsewhere on the board
unnamed: R9.1, U5.4 (ILIM)
unnamed: R7.2, R8.1, TP7.1, U5.3 (VSNS)
P1V1: C15.1, C17.1, C19.1, L2.2, R12.1, TP9.1; also elsewhere on the board
P1V8: C66.1, C67.1, C68.1, L3.2, R30.1, TP12.1; also elsewhere on the board
P2V5: C13.1, TP10.1, U8.5 (OUT); also elsewhere on the board
P3V3: C9.1, C11.1, C12.1, C65.1, J4.2, TP4.1, U5.7 (OUT), U7.1 (EN), U7.4 (VIN), U8.1 (IN), U8.3 (EN), U13.1 (EN), U13.4 (VIN); also elsewhere on the board
USB_3V3: C7.1, C8.1, C14.1, C16.1, C18.1, L1.2, R10.1, TP3.1, TP6.1, U5.6 (IN2)
USB_5V: C10.1, TP5.1, U6.1 (EN), U6.4 (VIN); also elsewhere on the board

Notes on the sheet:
The 400R value sets a current limit of 1.24A Current limit I_LIM = 500 / R_ILIM (in amps)
NB. Bulk capacitances C7 and C9 are likely redundant in this circuit !! That would follow the usage from the 64drive which doesn’t place bulk caps on either the inputs or the outputs
TLV62568DBV Vout = 0.6V * (1 + R1/R2), where R1 = top, R2 = bottom
N64 (IN1) has priority when >= 2.85V (VSNS > 0.8V) See TPS2111A datasheet, pg. 16, fig. 14

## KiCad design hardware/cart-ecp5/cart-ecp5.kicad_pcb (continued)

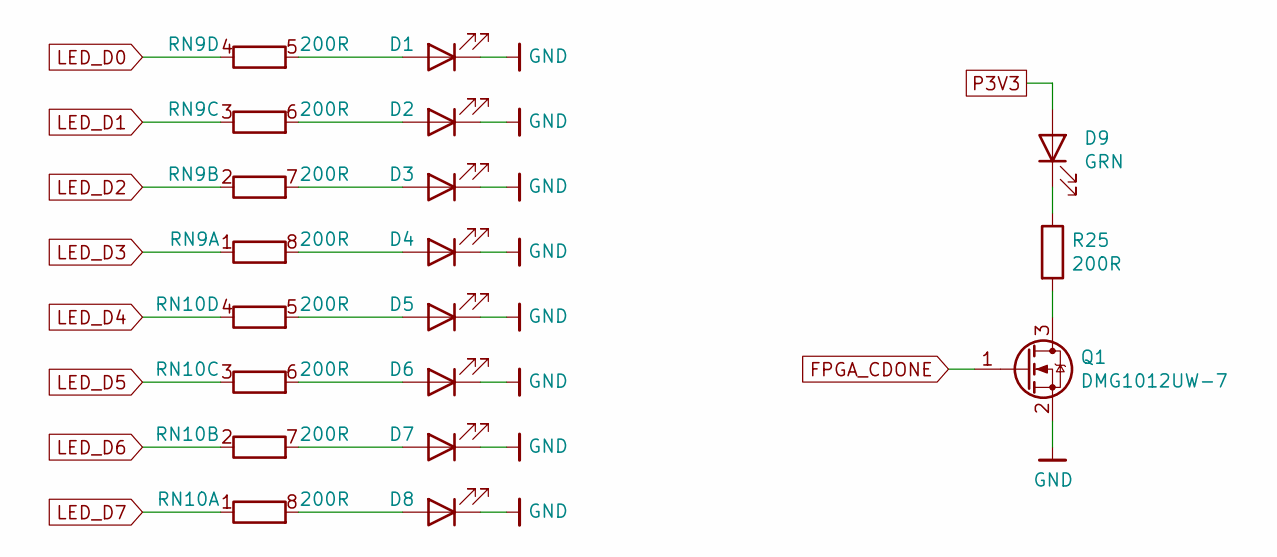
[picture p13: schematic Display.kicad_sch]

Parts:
D1, D2, D3, D4, D5, D6, D7, D8, D9: GRN; D_0603_1608Metric; MPN LTST-C191KGKT
Q1: DMG1012UW-7; SOT-323_SC-70; MPN DMG1012UW-7
R25: 200R; R_0402_1005Metric; MPN RC0402JR-07200RL
RN9, RN10: 200R; R_Array_Convex_4x0603; MPN YC164-JR-07200RL

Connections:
FPGA_CDONE: Q1.1 (G); also elsewhere on the board
GND: D1.1 (K), D2.1 (K), D3.1 (K), D4.1 (K), D5.1 (K), D6.1 (K), D7.1 (K), D8.1 (K), Q1.2 (S); also elsewhere on the board
LED_D0: RN9.4 (R4.1); also elsewhere on the board
LED_D1: RN9.3 (R3.1); also elsewhere on the board
LED_D2: RN9.2 (R2.1); also elsewhere on the board
LED_D3: RN9.1 (R1.1); also elsewhere on the board
LED_D4: RN10.4 (R4.1); also elsewhere on the board
LED_D5: RN10.3 (R3.1); also elsewhere on the board
LED_D6: RN10.2 (R2.1); also elsewhere on the board
LED_D7: RN10.1 (R1.1); also elsewhere on the board
unnamed: D1.2 (A), RN9.5 (R4.2)
unnamed: D2.2 (A), RN9.6 (R3.2)
unnamed: D3.2 (A), RN9.7 (R2.2)
unnamed: D4.2 (A), RN9.8 (R1.2)
unnamed: D5.2 (A), RN10.5 (R4.2)
unnamed: D6.2 (A), RN10.6 (R3.2)
unnamed: D7.2 (A), RN10.7 (R2.2)
unnamed: D8.2 (A), RN10.8 (R1.2)
unnamed: D9.1 (K), R25.1
unnamed: Q1.3 (D), R25.2
P3V3: D9.2 (A); also elsewhere on the board

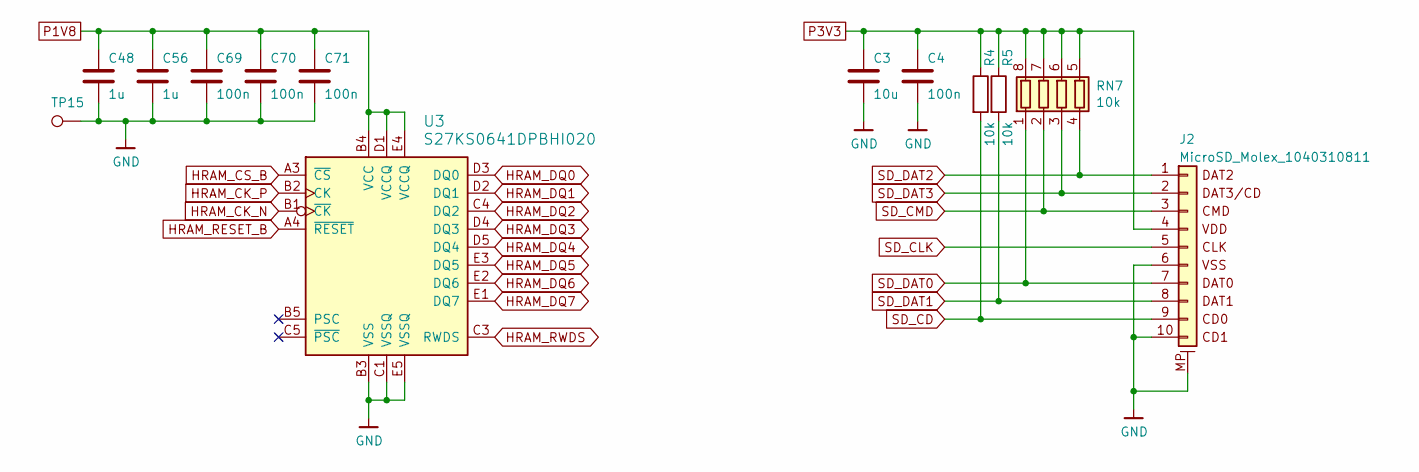
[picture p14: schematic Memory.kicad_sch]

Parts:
C3: 10u; C_0603_1608Metric; MPN CL10A106MQ8NNND
C4, C69, C70, C71: 100n; C_0402_1005Metric; MPN CL05B104KO5NNNC
C48, C56: 1u; C_0402_1005Metric; MPN CL05A105KO5NNNC
J2: MicroSD_Molex_1040310811; MPN 104031-0811
R4, R5: 10k; R_0402_1005Metric; MPN RC0402FR-0710KL
RN7: 10k; R_Array_Convex_4x0603; MPN YC164-FR-0710KL
TP15: TestPoint; TestPoint_Pad_D1.0mm
U3: S27KS0641DPBHI020; BGA-24_6.0x8.0mm_Layout5x5_P1.0mm_Pad0.4mm; MPN S27KS0641DPBHI020

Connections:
GND: C3.2, C4.2, C48.2, C56.2, C69.2, C70.2, C71.2, J2.6, J2.10 (DET), J2.MP (MountPin), TP15.1, U3.B3 (VSS), U3.C1 (VSSQ), U3.E5 (VSSQ); also elsewhere on the board
HRAM_CK_N: U3.B1 (~CK); also elsewhere on the board
HRAM_CK_P: U3.B2 (CK); also elsewhere on the board
HRAM_CS_B: U3.A3 (~CS); also elsewhere on the board
HRAM_DQ0: U3.D3 (DQ0); also elsewhere on the board
HRAM_DQ1: U3.D2 (DQ1); also elsewhere on the board
HRAM_DQ2: U3.C4 (DQ2); also elsewhere on the board
HRAM_DQ3: U3.D4 (DQ3); also elsewhere on the board
HRAM_DQ4: U3.D5 (DQ4); also elsewhere on the board
HRAM_DQ5: U3.E3 (DQ5); also elsewhere on the board
HRAM_DQ6: U3.E2 (DQ6); also elsewhere on the board
HRAM_DQ7: U3.E1 (DQ7); also elsewhere on the board
HRAM_RESET_B: U3.A4 (~RESET); also elsewhere on the board
HRAM_RWDS: U3.C3 (RWDS); also elsewhere on the board
P1V8: C48.1, C56.1, C69.1, C70.1, C71.1, U3.B4 (VCC), U3.D1 (VCCQ), U3.E4 (VCCQ); also elsewhere on the board
P3V3: C3.1, C4.1, J2.4, R4.1, R5.1, RN7.5 (R4.2), RN7.6 (R3.2), RN7.7 (R2.2), RN7.8 (R1.2); also elsewhere on the board
SD_CD: J2.9, R4.2; also elsewhere on the board
SD_CLK: J2.5; also elsewhere on the board
SD_CMD: J2.3, RN7.2 (R2.1); also elsewhere on the board
SD_DAT0: J2.7, RN7.1 (R1.1); also elsewhere on the board
SD_DAT1: J2.8, R5.2; also elsewhere on the board
SD_DAT2: J2.1, RN7.4 (R4.1); also elsewhere on the board
SD_DAT3: J2.2, RN7.3 (R3.1); also elsewhere on the board

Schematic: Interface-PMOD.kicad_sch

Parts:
J6: Conn_02x06_Odd_Even; PinSocket_2x06_P2.54mm_Horizontal

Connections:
GND: J6.3, J6.4; also elsewhere on the board
P3V3: J6.1, J6.2; also elsewhere on the board
PMOD_P1_D0: J6.11; also elsewhere on the board
PMOD_P1_D1: J6.9; also elsewhere on the board
PMOD_P1_D2: J6.7; also elsewhere on the board
PMOD_P1_D3: J6.5; also elsewhere on the board
PMOD_P1_D4: J6.12; also elsewhere on the board
PMOD_P1_D5: J6.10; also elsewhere on the board
PMOD_P1_D6: J6.8; also elsewhere on the board
PMOD_P1_D7: J6.6; also elsewhere on the board

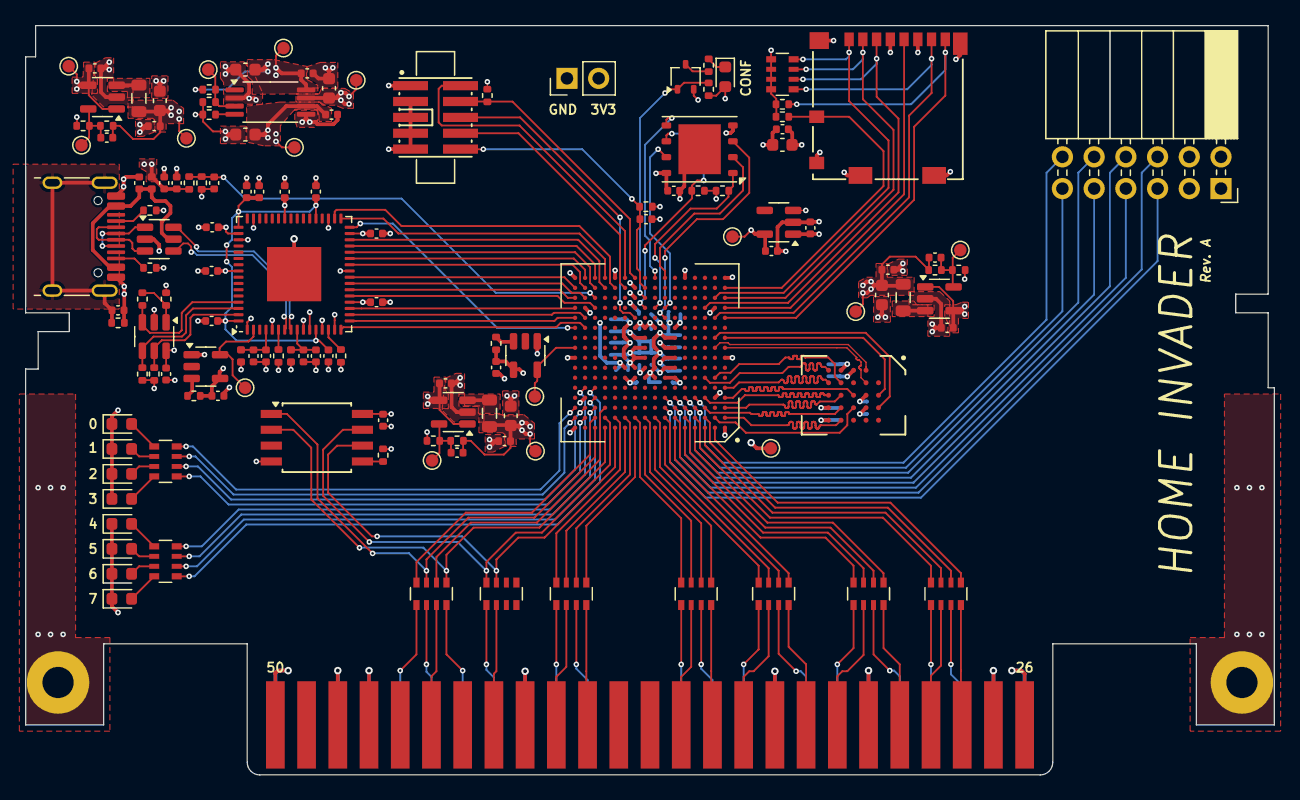
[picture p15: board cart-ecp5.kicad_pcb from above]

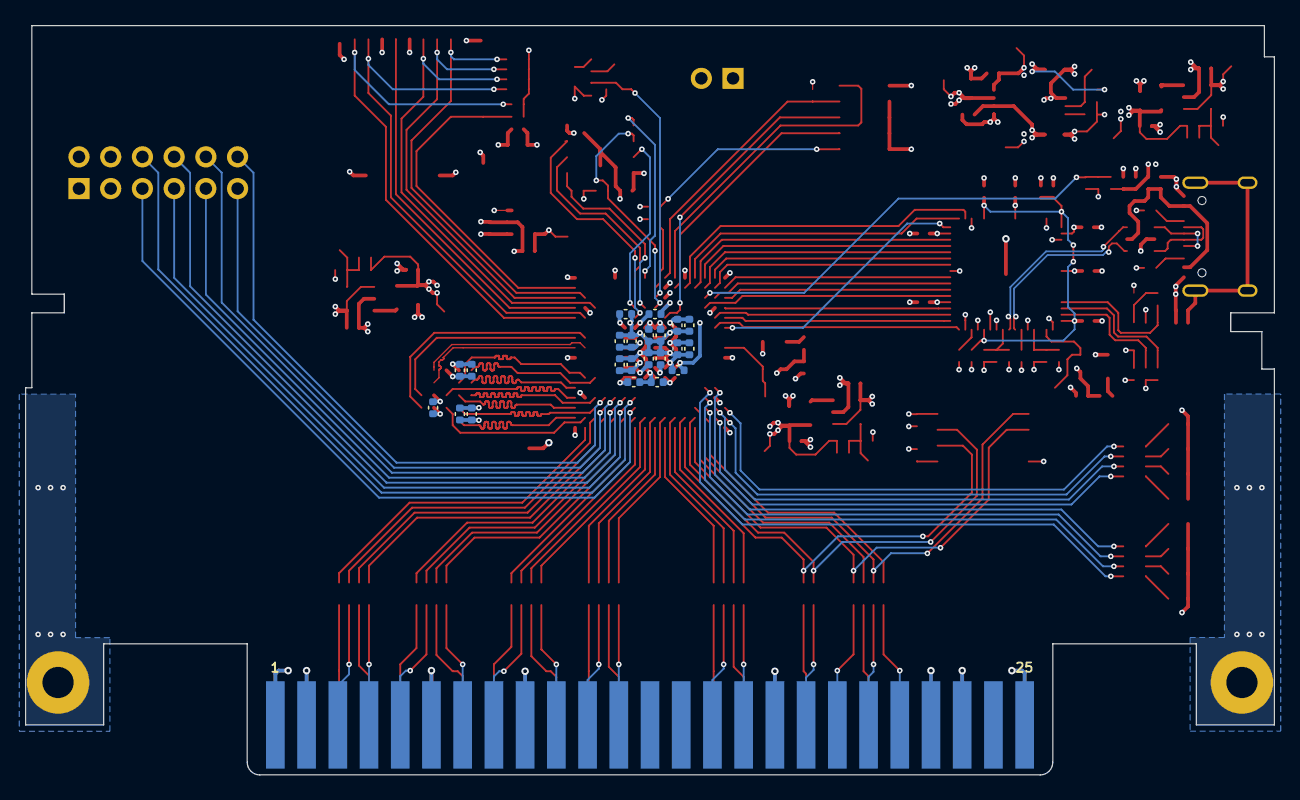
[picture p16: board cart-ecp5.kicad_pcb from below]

Board: 4 copper layers, 100.0 x 60.0 mm, 160 parts (22 on the bottom side), 165 nets.

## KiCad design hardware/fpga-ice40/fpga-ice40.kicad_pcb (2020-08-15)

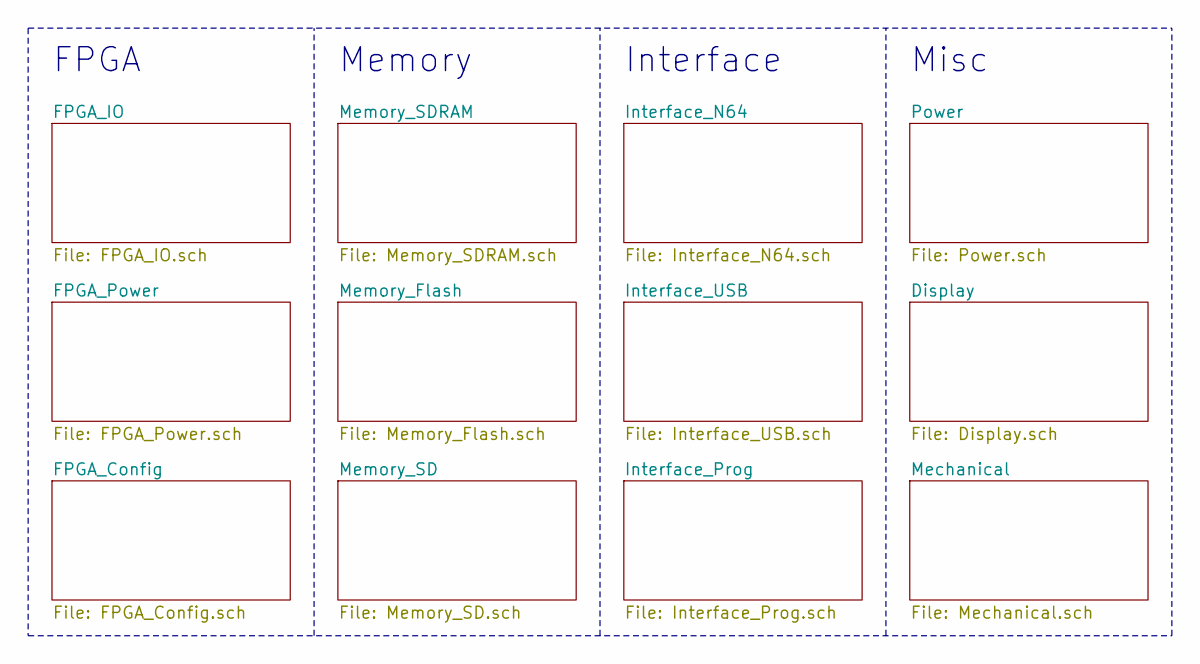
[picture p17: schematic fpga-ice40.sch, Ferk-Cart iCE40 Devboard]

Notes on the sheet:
Memory
Interface
Misc
FPGA

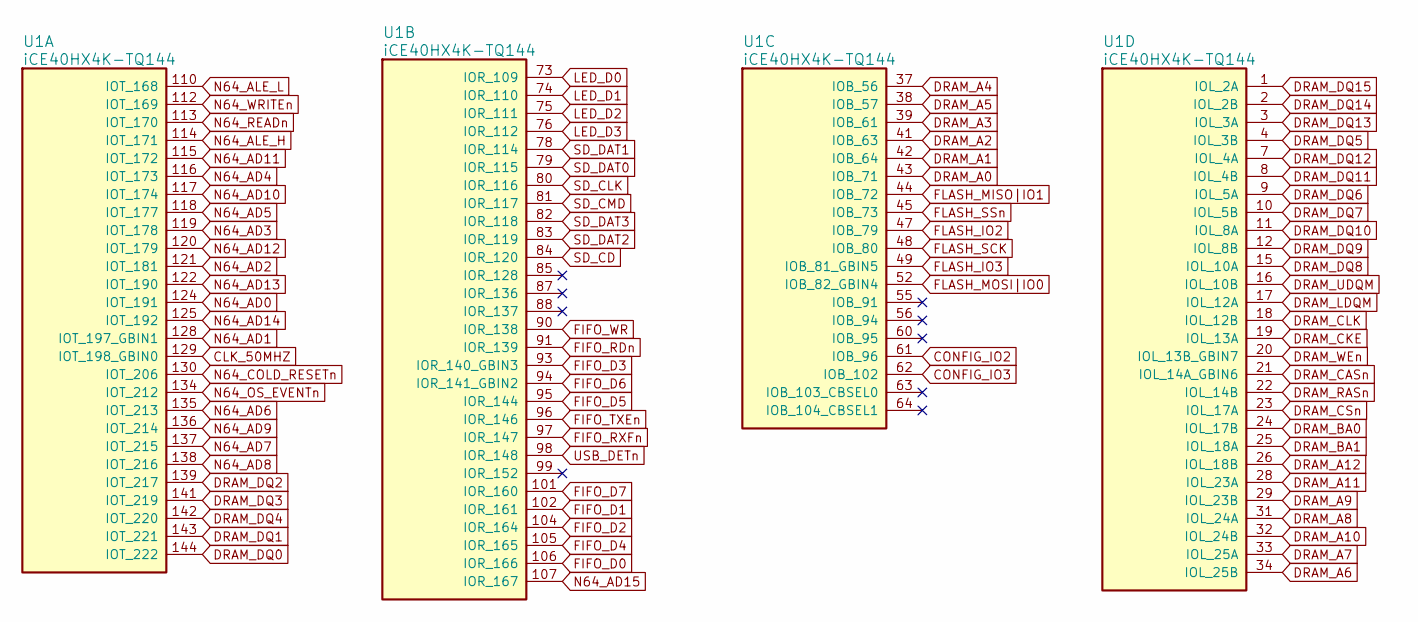
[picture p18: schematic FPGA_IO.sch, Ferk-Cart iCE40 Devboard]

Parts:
U1: iCE40HX4K-TQ144; TQFP-144_20x20mm_P0.5mm; MPN iCE40HX4K-TQ144

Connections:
CLK_50MHZ: U1.129 (IOT_198_GBIN0); also elsewhere on the board
CONFIG_IO2: U1.61 (IOB_96); also elsewhere on the board
CONFIG_IO3: U1.62 (IOB_102); also elsewhere on the board
DRAM_A0: U1.43 (IOB_71); also elsewhere on the board
DRAM_A1: U1.42 (IOB_64); also elsewhere on the board
DRAM_A2: U1.41 (IOB_63); also elsewhere on the board
DRAM_A3: U1.39 (IOB_61); also elsewhere on the board
DRAM_A4: U1.37 (IOB_56); also elsewhere on the board
DRAM_A5: U1.38 (IOB_57); also elsewhere on the board
DRAM_A6: U1.34 (IOL_25B); also elsewhere on the board
DRAM_A7: U1.33 (IOL_25A); also elsewhere on the board
DRAM_A8: U1.31 (IOL_24A); also elsewhere on the board
DRAM_A9: U1.29 (IOL_23B); also elsewhere on the board
DRAM_A10: U1.32 (IOL_24B); also elsewhere on the board
DRAM_A11: U1.28 (IOL_23A); also elsewhere on the board
DRAM_A12: U1.26 (IOL_18B); also elsewhere on the board
DRAM_BA0: U1.24 (IOL_17B); also elsewhere on the board
DRAM_BA1: U1.25 (IOL_18A); also elsewhere on the board
DRAM_CASn: U1.21 (IOL_14A_GBIN6); also elsewhere on the board
DRAM_CKE: U1.19 (IOL_13A); also elsewhere on the board
DRAM_CLK: U1.18 (IOL_12B); also elsewhere on the board
DRAM_CSn: U1.23 (IOL_17A); also elsewhere on the board
DRAM_DQ0: U1.144 (IOT_222); also elsewhere on the board
DRAM_DQ1: U1.143 (IOT_221); also elsewhere on the board
DRAM_DQ2: U1.139 (IOT_217); also elsewhere on the board
DRAM_DQ3: U1.141 (IOT_219); also elsewhere on the board
DRAM_DQ4: U1.142 (IOT_220); also elsewhere on the board
DRAM_DQ5: U1.4 (IOL_3B); also elsewhere on the board
DRAM_DQ6: U1.9 (IOL_5A); also elsewhere on the board
DRAM_DQ7: U1.10 (IOL_5B); also elsewhere on the board
DRAM_DQ8: U1.15 (IOL_10A); also elsewhere on the board
DRAM_DQ9: U1.12 (IOL_8B); also elsewhere on the board
DRAM_DQ10: U1.11 (IOL_8A); also elsewhere on the board
DRAM_DQ11: U1.8 (IOL_4B); also elsewhere on the board
DRAM_DQ12: U1.7 (IOL_4A); also elsewhere on the board
DRAM_DQ13: U1.3 (IOL_3A); also elsewhere on the board
DRAM_DQ14: U1.2 (IOL_2B); also elsewhere on the board
DRAM_DQ15: U1.1 (IOL_2A); also elsewhere on the board
DRAM_LDQM: U1.17 (IOL_12A); also elsewhere on the board
DRAM_RASn: U1.22 (IOL_14B); also elsewhere on the board
DRAM_UDQM: U1.16 (IOL_10B); also elsewhere on the board
DRAM_WEn: U1.20 (IOL_13B_GBIN7); also elsewhere on the board
FIFO_D0: U1.106 (IOR_166); also elsewhere on the board
FIFO_D1: U1.102 (IOR_161); also elsewhere on the board
FIFO_D2: U1.104 (IOR_164); also elsewhere on the board
FIFO_D3: U1.93 (IOR_140_GBIN3); also elsewhere on the board
FIFO_D4: U1.105 (IOR_165); also elsewhere on the board
FIFO_D5: U1.95 (IOR_144); also elsewhere on the board
FIFO_D6: U1.94 (IOR_141_GBIN2); also elsewhere on the board
FIFO_D7: U1.101 (IOR_160); also elsewhere on the board
FIFO_RDn: U1.91 (IOR_139); also elsewhere on the board
FIFO_RXFn: U1.97 (IOR_147); also elsewhere on the board
FIFO_TXEn: U1.96 (IOR_146); also elsewhere on the board
FIFO_WR: U1.90 (IOR_138); also elsewhere on the board
FLASH_IO2: U1.47 (IOB_79); also elsewhere on the board
FLASH_IO3: U1.49 (IOB_81_GBIN5); also elsewhere on the board
FLASH_MISO|IO1: U1.44 (IOB_72); also elsewhere on the board
FLASH_MOSI|IO0: U1.52 (IOB_82_GBIN4); also elsewhere on the board
FLASH_SCK: U1.48 (IOB_80); also elsewhere on the board
FLASH_SSn: U1.45 (IOB_73); also elsewhere on the board
LED_D0: U1.73 (IOR_109); also elsewhere on the board
LED_D1: U1.74 (IOR_110); also elsewhere on the board
LED_D2: U1.75 (IOR_111); also elsewhere on the board
LED_D3: U1.76 (IOR_112); also elsewhere on the board
N64_AD0: U1.124 (IOT_191); also elsewhere on the board
N64_AD1: U1.128 (IOT_197_GBIN1); also elsewhere on the board
N64_AD2: U1.121 (IOT_181); also elsewhere on the board
N64_AD3: U1.119 (IOT_178); also elsewhere on the board
N64_AD4: U1.116 (IOT_173); also elsewhere on the board
N64_AD5: U1.118 (IOT_177); also elsewhere on the board
N64_AD6: U1.135 (IOT_213); also elsewhere on the board
N64_AD7: U1.137 (IOT_215); also elsewhere on the board
N64_AD8: U1.138 (IOT_216); also elsewhere on the board
N64_AD9: U1.136 (IOT_214); also elsewhere on the board
N64_AD10: U1.117 (IOT_174); also elsewhere on the board
N64_AD11: U1.115 (IOT_172); also elsewhere on the board
N64_AD12: U1.120 (IOT_179); also elsewhere on the board
N64_AD13: U1.122 (IOT_190); also elsewhere on the board
N64_AD14: U1.125 (IOT_192); also elsewhere on the board
N64_AD15: U1.107 (IOR_167); also elsewhere on the board
N64_ALE_H: U1.114 (IOT_171); also elsewhere on the board
N64_ALE_L: U1.110 (IOT_168); also elsewhere on the board
N64_COLD_RESETn: U1.130 (IOT_206); also elsewhere on the board
N64_OS_EVENTn: U1.134 (IOT_212); also elsewhere on the board
N64_READn: U1.113 (IOT_170); also elsewhere on the board
N64_WRITEn: U1.112 (IOT_169); also elsewhere on the board
SD_CD: U1.84 (IOR_120); also elsewhere on the board
SD_CLK: U1.80 (IOR_116); also elsewhere on the board
SD_CMD: U1.81 (IOR_117); also elsewhere on the board
SD_DAT0: U1.79 (IOR_115); also elsewhere on the board
SD_DAT1: U1.78 (IOR_114); also elsewhere on the board
SD_DAT2: U1.83 (IOR_119); also elsewhere on the board
SD_DAT3: U1.82 (IOR_118); also elsewhere on the board
USB_DETn: U1.98 (IOR_148); also elsewhere on the board


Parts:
C1, C5: 10u; C_0805_2012Metric; MPN CL21A106KAYNNNE
C2, C6: 22u, 6V3; CP_EIA-2012-15_AVX-P; MPN TAJP226M006RNJ
C3, C4, C51: 10u; C_0805_2012Metric
C52, C53: 100n; C_0603_1608Metric
JP1, JP2, JP3: SolderJumper_2_Open; SolderJumper-2_P1.3mm_Open_TrianglePad1.0x1.5mm
R9, R12, R14: R; R_0603_1608Metric
U2: AZ1117-3.3; SOT-223-3_TabPin2; MPN AZ1117H-3.3TRE1
U3: AZ1117-1.2; SOT-223-3_TabPin2; MPN AZ1117H-1.2TRE1
U12: TPS2111A; TSSOP-8_4.4x3mm_P0.65mm

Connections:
GND: C1.2, C2.2, C3.2, C4.2, C5.2, C6.2, C51.2, C52.2, C53.2, R12.2, R14.2, U2.1 (GND), U3.1 (GND), U12.2 (D1), U12.5 (GND); also elsewhere on the board
MUX_3V3: C51.1, JP1.1 (A), U12.7 (OUT)
N64_3V3: C3.1, C52.1, JP2.1 (A), U12.8 (IN1); also elsewhere on the board
unnamed: R9.2, R12.1, U12.3 (VSNS)
unnamed: R14.1, U12.4 (ILIM)
P1V2: C6.1, U3.2 (VO); also elsewhere on the board
P3V3: C5.1, JP1.2 (B), JP2.2 (B), JP3.2 (B), U3.3 (VI); also elsewhere on the board
USB_3V3: C2.1, C4.1, C53.1, JP3.1 (A), R9.1, U2.2 (VO), U12.6 (IN2)
USB_5V: C1.1, U2.3 (VI); also elsewhere on the board

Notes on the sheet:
Tantalum


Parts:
C7, C8, C9, C10, C11, C12, C13: 100n; C_0603_1608Metric; MPN CL10B104KB8NNNC
R15, R16, R17, R18: 60R; R_0603_1608Metric
RN11, RN12, RN13, RN14, RN15, RN16, RN17, RN18, RN19: 60R; R_Array_Convex_4x0603
U4: IS42S16320F-7TL; TSOP-II-54_22.2x10.16mm_P0.8mm; MPN IS42S16320F-7TL

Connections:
/Memory_SDRAM/A0: RN12.8 (R1.2), U4.23 (A0)
/Memory_SDRAM/A1: RN12.7 (R2.2), U4.24 (A1)
/Memory_SDRAM/A2: RN12.6 (R3.2), U4.25 (A2)
/Memory_SDRAM/A3: RN12.5 (R4.2), U4.26 (A3)
/Memory_SDRAM/A4: RN11.8 (R1.2), U4.29 (A4)
/Memory_SDRAM/A5: RN11.7 (R2.2), U4.30 (A5)
/Memory_SDRAM/A6: RN11.6 (R3.2), U4.31 (A6)
/Memory_SDRAM/A7: RN11.5 (R4.2), U4.32 (A7)
/Memory_SDRAM/A8: RN13.8 (R1.2), U4.33 (A8)
/Memory_SDRAM/A9: RN13.7 (R2.2), U4.34 (A9)
/Memory_SDRAM/A10: RN14.5 (R4.2), U4.22 (A10/AP)
/Memory_SDRAM/A11: RN13.6 (R3.2), U4.35 (A11)
/Memory_SDRAM/A12: RN13.5 (R4.2), U4.36 (A12)
/Memory_SDRAM/BA0: RN14.7 (R2.2), U4.20 (BA0)
/Memory_SDRAM/BA1: RN14.6 (R3.2), U4.21 (BA1)
/Memory_SDRAM/CASn: RN15.6 (R3.2), U4.17 (~CAS)
/Memory_SDRAM/CKE: R15.1, U4.37 (CKE)
/Memory_SDRAM/CLK: R16.1, U4.38 (CLK)
/Memory_SDRAM/CSn: RN14.8 (R1.2), U4.19 (~CS)
/Memory_SDRAM/DQ0: RN19.8 (R1.2), U4.2 (DQ0)
/Memory_SDRAM/DQ1: RN19.7 (R2.2), U4.4 (DQ1)
/Memory_SDRAM/DQ2: RN19.6 (R3.2), U4.5 (DQ2)
/Memory_SDRAM/DQ3: RN19.5 (R4.2), U4.7 (DQ3)
/Memory_SDRAM/DQ4: RN17.8 (R1.2), U4.8 (DQ4)
/Memory_SDRAM/DQ5: RN17.7 (R2.2), U4.10 (DQ5)
/Memory_SDRAM/DQ6: RN17.6 (R3.2), U4.11 (DQ6)
/Memory_SDRAM/DQ7: RN17.5 (R4.2), U4.13 (DQ7)
/Memory_SDRAM/DQ8: RN16.8 (R1.2), U4.42 (DQ8)
/Memory_SDRAM/DQ9: RN16.7 (R2.2), U4.44 (DQ9)
/Memory_SDRAM/DQ10: RN16.6 (R3.2), U4.45 (DQ10)
/Memory_SDRAM/DQ11: RN16.5 (R4.2), U4.47 (DQ11)
/Memory_SDRAM/DQ12: RN18.8 (R1.2), U4.48 (DQ12)
/Memory_SDRAM/DQ13: RN18.7 (R2.2), U4.50 (DQ13)
/Memory_SDRAM/DQ14: RN18.6 (R3.2), U4.51 (DQ14)
/Memory_SDRAM/DQ15: RN18.5 (R4.2), U4.53 (DQ15)
/Memory_SDRAM/LDQM: R17.1, U4.15 (DQML)
/Memory_SDRAM/RASn: RN15.5 (R4.2), U4.18 (~RAS)
/Memory_SDRAM/UDQM: R18.1, U4.39 (DQMH)
/Memory_SDRAM/WEn: RN15.7 (R2.2), U4.16 (~WE)
DRAM_A0: RN12.1 (R1.1); also elsewhere on the board
DRAM_A1: RN12.2 (R2.1); also elsewhere on the board
DRAM_A2: RN12.3 (R3.1); also elsewhere on the board
DRAM_A3: RN12.4 (R4.1); also elsewhere on the board
DRAM_A4: RN11.1 (R1.1); also elsewhere on the board
DRAM_A5: RN11.2 (R2.1); also elsewhere on the board
DRAM_A6: RN11.3 (R3.1); also elsewhere on the board
DRAM_A7: RN11.4 (R4.1); also elsewhere on the board
DRAM_A8: RN13.1 (R1.1); also elsewhere on the board
DRAM_A9: RN13.2 (R2.1); also elsewhere on the board
DRAM_A10: RN14.4 (R4.1); also elsewhere on the board
DRAM_A11: RN13.3 (R3.1); also elsewhere on the board
DRAM_A12: RN13.4 (R4.1); also elsewhere on the board
DRAM_BA0: RN14.2 (R2.1); also elsewhere on the board
DRAM_BA1: RN14.3 (R3.1); also elsewhere on the board
DRAM_CASn: RN15.3 (R3.1); also elsewhere on the board
DRAM_CKE: R15.2; also elsewhere on the board
DRAM_CLK: R16.2; also elsewhere on the board
DRAM_CSn: RN14.1 (R1.1); also elsewhere on the board
DRAM_DQ0: RN19.1 (R1.1); also elsewhere on the board
DRAM_DQ1: RN19.2 (R2.1); also elsewhere on the board
DRAM_DQ2: RN19.3 (R3.1); also elsewhere on the board
DRAM_DQ3: RN19.4 (R4.1); also elsewhere on the board
DRAM_DQ4: RN17.1 (R1.1); also elsewhere on the board
DRAM_DQ5: RN17.2 (R2.1); also elsewhere on the board
DRAM_DQ6: RN17.3 (R3.1); also elsewhere on the board
DRAM_DQ7: RN17.4 (R4.1); also elsewhere on the board
DRAM_DQ8: RN16.1 (R1.1); also elsewhere on the board
DRAM_DQ9: RN16.2 (R2.1); also elsewhere on the board
DRAM_DQ10: RN16.3 (R3.1); also elsewhere on the board
DRAM_DQ11: RN16.4 (R4.1); also elsewhere on the board
DRAM_DQ12: RN18.1 (R1.1); also elsewhere on the board
DRAM_DQ13: RN18.2 (R2.1); also elsewhere on the board
DRAM_DQ14: RN18.3 (R3.1); also elsewhere on the board
DRAM_DQ15: RN18.4 (R4.1); also elsewhere on the board
DRAM_LDQM: R17.2; also elsewhere on the board
DRAM_RASn: RN15.4 (R4.1); also elsewhere on the board
DRAM_UDQM: R18.2; also elsewhere on the board
DRAM_WEn: RN15.2 (R2.1); also elsewhere on the board
GND: C7.2, C8.2, C9.2, C10.2, C11.2, C12.2, C13.2, U4.6 (VSSQ), U4.12 (VSSQ), U4.28 (VSS), U4.41 (VSS), U4.46 (VSSQ), U4.52 (VSSQ), U4.54 (VSS); also elsewhere on the board
P3V3: C7.1, C8.1, C9.1, C10.1, C11.1, C12.1, C13.1, U4.1 (VDD), U4.3 (VDDQ), U4.9 (VDDQ), U4.14 (VDD), U4.27 (VDD), U4.43 (VDDQ), U4.49 (VDDQ); also elsewhere on the board


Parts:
C14, C15: 100n; C_0603_1608Metric; MPN CL10B104KB8NNNC
RN1, RN2: 10k; R_Array_Convex_4x0603; MPN YC164-JR-0710KL
U5, U7: S25FL256SAGMFI01x; SOIC-16W_7.5x10.3mm_P1.27mm; MPN S25FL256SAGMFI013
U6, U8: W25Q32JVSSIM; SOIC-8_5.275x5.275mm_P1.27mm__No_CrtYd; MPN W25Q32JVSSIM (TR)

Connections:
CONFIG_IO2: RN1.2 (R2.1), U5.9 (~WP~/IO2), U6.3 (~WP~/IO2); also elsewhere on the board
CONFIG_IO3: RN1.4 (R4.1), U5.1 (~HOLD~/IO3), U6.7 (~HLD~/~RST~/IO3); also elsewhere on the board
CONFIG_MISO|IO1: U5.8 (SO/IO1), U6.2 (DO/IO1); also elsewhere on the board
CONFIG_MOSI|IO0: U5.15 (SI/IO0), U6.5 (DI/IO0); also elsewhere on the board
CONFIG_SCK: RN1.3 (R3.1), U5.16 (SCK), U6.6 (CLK); also elsewhere on the board
CONFIG_SSn: RN1.1 (R1.1), U5.7 (~CS), U6.1 (~CS); also elsewhere on the board
FLASH_IO2: RN2.2 (R2.1), U7.9 (~WP~/IO2), U8.3 (~WP~/IO2); also elsewhere on the board
FLASH_IO3: RN2.4 (R4.1), U7.1 (~HOLD~/IO3), U8.7 (~HLD~/~RST~/IO3); also elsewhere on the board
FLASH_MISO|IO1: U7.8 (SO/IO1), U8.2 (DO/IO1); also elsewhere on the board
FLASH_MOSI|IO0: U7.15 (SI/IO0), U8.5 (DI/IO0); also elsewhere on the board
FLASH_SCK: RN2.3 (R3.1), U7.16 (SCK), U8.6 (CLK); also elsewhere on the board
FLASH_SSn: RN2.1 (R1.1), U7.7 (~CS), U8.1 (~CS); also elsewhere on the board
GND: C14.2, C15.2, U5.10 (VSS), U6.4 (GND), U7.10 (VSS), U8.4 (GND); also elsewhere on the board
P3V3: C14.1, C15.1, RN1.5 (R4.2), RN1.6 (R3.2), RN1.7 (R2.2), RN1.8 (R1.2), RN2.5 (R4.2), RN2.6 (R3.2), RN2.7 (R2.2), RN2.8 (R1.2), U5.2 (VCC), U5.3 ((~RESET~)), U5.14 ((VIO)), U6.8 (VCC), U7.2 (VCC), U7.3 ((~RESET~)), U7.14 ((VIO)), U8.8 (VCC); also elsewhere on the board


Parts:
C16: 10u; C_0805_2012Metric; MPN CL21A106KAYNNNE
C17: 100n; C_0603_1608Metric; MPN CL10B104KB8NNNC
J2: MicroSD_Molex_1040310811; MPN 104031-0811
R1, R8: 10k; R_0603_1608Metric; MPN RC0603FR-0710KL
RN3: 10k; R_Array_Convex_4x0603; MPN YC164-JR-0710KL

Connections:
GND: C16.2, C17.2, J2.6, J2.10 (DET), J2.MP (MountPin); also elsewhere on the board
P3V3: C16.1, C17.1, J2.4, R1.1, R8.1, RN3.5 (R4.2), RN3.6 (R3.2), RN3.7 (R2.2), RN3.8 (R1.2); also elsewhere on the board
SD_CD: J2.9, R8.2; also elsewhere on the board
SD_CLK: J2.5; also elsewhere on the board
SD_CMD: J2.3, RN3.2 (R2.1); also elsewhere on the board
SD_DAT0: J2.7, RN3.1 (R1.1); also elsewhere on the board
SD_DAT1: J2.8, R1.2; also elsewhere on the board
SD_DAT2: J2.1, RN3.4 (R4.1); also elsewhere on the board
SD_DAT3: J2.2, RN3.3 (R3.1); also elsewhere on the board

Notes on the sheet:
DNP


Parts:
J3, J4: FTSH-105-01-L-DV-K; Samtec_FTSH-105-XX-X-DV-Mating; MPN FTSH-105-01-L-DV-K

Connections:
CONFIG_CRESETn: J3.2; also elsewhere on the board
CONFIG_IO2: J3.9; also elsewhere on the board
CONFIG_IO3: J3.1; also elsewhere on the board
CONFIG_MISO|IO1: J3.7; also elsewhere on the board
CONFIG_MOSI|IO0: J3.5; also elsewhere on the board
CONFIG_SCK: J3.3; also elsewhere on the board
CONFIG_SSn: J3.10; also elsewhere on the board
FLASH_CRESETn: J4.2; also elsewhere on the board
FLASH_IO2: J4.9; also elsewhere on the board
FLASH_IO3: J4.1; also elsewhere on the board
FLASH_MISO|IO1: J4.7; also elsewhere on the board
FLASH_MOSI|IO0: J4.5; also elsewhere on the board
FLASH_SCK: J4.3; also elsewhere on the board
FLASH_SSn: J4.10; also elsewhere on the board
FPGA_CDONE: J3.8, J4.8; also elsewhere on the board
GND: J3.6, J4.6; also elsewhere on the board
P3V3: J3.4, J4.4; also elsewhere on the board

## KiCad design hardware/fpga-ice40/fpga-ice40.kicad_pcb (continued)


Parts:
C18, C21, C22, C48, C50, C55: 100n; C_0603_1608Metric; MPN CL10B104KB8NNNC
C19: 4u7; C_0603_1608Metric; MPN CL10A475KA8NQNC
C20: 10n; C_0603_1608Metric; MPN CL10B103KC8NNNC
C49: DNP; C_0603_1608Metric
FB1: 33R, 3A; L_0603_1608Metric; MPN BLM18PG330SN1D
J5: USB_B_Micro; USB_Micro-B_Molex_47346-0001; MPN 47346-0001
R2: 100k; R_0603_1608Metric; MPN RC0603JR-07100KL
R3: 6k8; R_0603_1608Metric; MPN RC0603FR-076K8L
R4, R5: 10k; R_0603_1608Metric; MPN RC0603FR-0710KL
U9: FT245RL; SSOP-28_5.3x10.2mm_P0.65mm; MPN FT245RL-REEL
U11: USBLC6-2SC6; SOT-23-6
X2: 12MHz; Oscillator_2.5x2.0; MPN ECS-2520MV-120-BN-TR

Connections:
/Interface_USB/USB_3V3: C22.1, U9.17 (3V3OUT)
/Interface_USB/USB_CLK: U9.27 (OSCI), X2.3 (OUT)
/Interface_USB/USB_PWRENn: R4.2, U9.12 (~PWREN)
/Interface_USB/USB_SHD: C20.1, J5.6 (Shield), R2.2
/Interface_USB/USB_VBUS: C18.1, FB1.2, J5.1 (VBUS), U11.5 (VBUS)
FIFO_D0: U9.1 (D0); also elsewhere on the board
FIFO_D1: U9.5 (D1); also elsewhere on the board
FIFO_D2: U9.3 (D2); also elsewhere on the board
FIFO_D3: U9.11 (D3); also elsewhere on the board
FIFO_D4: U9.2 (D4); also elsewhere on the board
FIFO_D5: U9.9 (D5); also elsewhere on the board
FIFO_D6: U9.10 (D6); also elsewhere on the board
FIFO_D7: U9.6 (D7); also elsewhere on the board
FIFO_RDn: U9.13 (~RD); also elsewhere on the board
FIFO_RXFn: U9.23 (~RXF); also elsewhere on the board
FIFO_TXEn: U9.22 (~TXE); also elsewhere on the board
FIFO_WR: U9.14 (WR); also elsewhere on the board
GND: C18.2, C19.2, C20.2, C21.2, C22.2, C48.2, C49.2, C50.2, C55.2, J5.5 (GND), R2.1, R5.2, U9.7 (GND), U9.18 (GND), U9.21 (GND), U9.25 (AGND), U9.26 (TEST), U11.2 (GND), X2.2 (GND); also elsewhere on the board
P3V3: C21.1, C50.1, C55.1, R4.1, U9.4 (VCCIO), U9.20 (VCC), X2.1 (Tri-State), X2.4 (VDD); also elsewhere on the board
USB_5V: C19.1, C48.1, FB1.1, R3.1; also elsewhere on the board
USB_D+: U9.15 (USBDP), U11.4 (IO2)
USB_D-: U9.16 (USBDM), U11.6 (IO1)
USB_DETn: C49.1, R3.2, R5.1, U9.19 (~RESET); also elsewhere on the board
xUSB_D+: J5.3 (D+), U11.3 (IO2)
xUSB_D-: J5.2 (D-), U11.1 (IO1)

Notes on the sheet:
USB_DETn < 3.3V for compatibility with FPGA IO bank
USBLC6 requires 100n (C18) on VBUS, not 10n as would be expected

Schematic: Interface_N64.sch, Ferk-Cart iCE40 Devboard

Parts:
C54: 100n; C_0603_1608Metric
J6: Conn_02x20_Odd_Even; PinHeader_2x20_P2.54mm_Horizontal; MPN C124369
RN4, RN5, RN6, RN7, RN8, RN9: 33R, 1%; R_Array_Convex_4x0603; MPN YC164-FR-0733RL

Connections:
GND: C54.2, J6.12, J6.14, J6.16, J6.18, J6.30; also elsewhere on the board
N64_3V3: J6.13, J6.15, J6.17; also elsewhere on the board
N64_AD0: RN4.7 (R2.2); also elsewhere on the board
N64_AD1: RN4.5 (R4.2); also elsewhere on the board
N64_AD2: RN6.7 (R2.2); also elsewhere on the board
N64_AD3: RN6.5 (R4.2); also elsewhere on the board
N64_AD4: RN5.7 (R2.2); also elsewhere on the board
N64_AD5: RN5.5 (R4.2); also elsewhere on the board
N64_AD6: RN7.8 (R1.2); also elsewhere on the board
N64_AD7: RN7.6 (R3.2); also elsewhere on the board
N64_AD8: RN7.5 (R4.2); also elsewhere on the board
N64_AD9: RN7.7 (R2.2); also elsewhere on the board
N64_AD10: RN5.6 (R3.2); also elsewhere on the board
N64_AD11: RN5.8 (R1.2); also elsewhere on the board
N64_AD12: RN6.6 (R3.2); also elsewhere on the board
N64_AD13: RN6.8 (R1.2); also elsewhere on the board
N64_AD14: RN4.6 (R3.2); also elsewhere on the board
N64_AD15: RN4.8 (R1.2); also elsewhere on the board
N64_ALE_H: RN8.5 (R4.2); also elsewhere on the board
N64_ALE_L: RN8.8 (R1.2); also elsewhere on the board
N64_COLD_RESETn: RN9.7 (R2.2); also elsewhere on the board
N64_OS_EVENTn: RN9.8 (R1.2); also elsewhere on the board
N64_READn: RN8.6 (R3.2); also elsewhere on the board
N64_WRITEn: RN8.7 (R2.2); also elsewhere on the board
P3V3: C54.1; also elsewhere on the board
xN64_AD0: J6.39, RN4.2 (R2.1)
xN64_AD1: J6.37, RN4.4 (R4.1)
xN64_AD2: J6.35, RN6.2 (R2.1)
xN64_AD3: J6.33, RN6.4 (R4.1)
xN64_AD4: J6.25, RN5.2 (R2.1)
xN64_AD5: J6.23, RN5.4 (R4.1)
xN64_AD6: J6.21, RN7.1 (R1.1)
xN64_AD7: J6.19, RN7.3 (R3.1)
xN64_AD8: J6.20, RN7.4 (R4.1)
xN64_AD9: J6.22, RN7.2 (R2.1)
xN64_AD10: J6.24, RN5.3 (R3.1)
xN64_AD11: J6.26, RN5.1 (R1.1)
xN64_AD12: J6.34, RN6.3 (R3.1)
xN64_AD13: J6.36, RN6.1 (R1.1)
xN64_AD14: J6.38, RN4.3 (R3.1)
xN64_AD15: J6.40, RN4.1 (R1.1)
xN64_ALE_H: J6.27, RN8.4 (R4.1)
xN64_ALE_L: J6.31, RN8.1 (R1.1)
xN64_COLD_RESETn: J6.5, RN9.2 (R2.1)
xN64_OS_EVENTn: J6.6, RN9.1 (R1.1)
xN64_READn: J6.28, RN8.3 (R3.1)
xN64_WRITEn: J6.32, RN8.2 (R2.1)

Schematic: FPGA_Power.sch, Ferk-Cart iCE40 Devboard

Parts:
C23, C30, C42: 10u; C_0603_1608Metric; MPN CL10A106MQ8NNNC
C24, C46: 1u; C_0603_1608Metric; MPN CL10A105KB8NNNC
C25, C26, C27, C28, C29, C31, C33, C34, C35, C36, C37, C38, C39, C40, C41, C43: 100n; C_0603_1608Metric; MPN CL10B104KB8NNNC
C32: 10u; C_0805_2012Metric; MPN CL21A106KAYNNNE
C45, C47: 10n; C_0603_1608Metric; MPN CL10B103KC8NNNC
D1: ~~800mVf; D_SOD-123F; MPN SBR2M60S1F-7
R6, R7: 100R; R_0603_1608Metric; MPN RC0603FR-07100RL
U1: iCE40HX4K-TQ144; TQFP-144_20x20mm_P0.5mm; MPN iCE40HX4K-TQ144

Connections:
GND: C23.2, C24.2, C25.2, C26.2, C27.2, C28.2, C29.2, C32.2, C33.2, C34.2, C35.2, C36.2, C37.2, C38.2, C39.2, C40.2, C41.2, C45.2, C46.2, C47.2, U1.5 (GND), U1.13 (GND), U1.14 (GND), U1.59 (GND), U1.69 (GND), U1.86 (GND), U1.103 (GND), U1.132 (GND), U1.140 (GND); also elsewhere on the board
P1V2: C23.1, C24.1, C25.1, C26.1, C27.1, C28.1, C45.1, R6.2, R7.2, U1.27 (VCC), U1.40 (VCC), U1.92 (VCC), U1.111 (VCC); also elsewhere on the board
P3V3: C32.1, C33.1, C34.1, C35.1, C36.1, C37.1, C38.1, C39.1, C40.1, C41.1, C46.1, C47.1, D1.2 (A), U1.6 (VCCIO_3), U1.30 (VCCIO_3), U1.46 (VCCIO_2), U1.57 (VCCIO_2), U1.72 (VCC_SPI), U1.89 (VCCIO_1), U1.100 (VCCIO_1), U1.123 (VCCIO_0), U1.131 (VCCIO_0); also elsewhere on the board
VCC2V5: C29.1, D1.1 (K), U1.108 (VPP_2V5)
VCCGND0: C30.2, C31.2, U1.53 (GNDPLL0)
VCCGND1: C42.2, C43.2, U1.127 (GNDPLL1)
VCCPLL0: C30.1, C31.1, R6.1, U1.54 (VCCPLL0)
VCCPLL1: C42.1, C43.1, R7.1, U1.126 (VCCPLL1)

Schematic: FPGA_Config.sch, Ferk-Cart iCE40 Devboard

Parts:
C44: 100n; C_0603_1608Metric; MPN CL10B104KB8NNNC
RN10: 10k; R_Array_Convex_4x0603; MPN YC164-JR-0710KL
U1: iCE40HX4K-TQ144; TQFP-144_20x20mm_P0.5mm; MPN iCE40HX4K-TQ144
U10: MC74HC1G08DTT1G; SOT-23-5; MPN MC74HC1G08DTT1G
X1: 50MHz; Oscillator_2.5x2.0; MPN ECS-2520MV-500-BN-TR

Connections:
CLK_50MHZ: X1.3 (OUT); also elsewhere on the board
CONFIG_CRESETn: RN10.3, U10.2; also elsewhere on the board
CONFIG_MISO|IO1: U1.68 (IOB_106_SDI); also elsewhere on the board
CONFIG_MOSI|IO0: U1.67 (IOB_105_SDO); also elsewhere on the board
CONFIG_SCK: U1.70 (IOB_107_SCK); also elsewhere on the board
CONFIG_SSn: U1.71 (IOB_108_SS); also elsewhere on the board
FLASH_CRESETn: RN10.2, U10.1; also elsewhere on the board
FPGA_CDONE: RN10.1, U1.65 (CDONE); also elsewhere on the board
FPGA_CRESETn: RN10.4, U1.66 (~CRESET_B), U10.4
GND: C44.2, U10.3 (GND), X1.2 (GND); also elsewhere on the board
P3V3: C44.1, RN10.5, RN10.6, RN10.7, RN10.8, U10.5 (VCC), X1.1 (Tri-State), X1.4 (VDD); also elsewhere on the board

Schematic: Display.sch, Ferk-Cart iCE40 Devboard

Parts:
D2, D3, D4, D5, D6, D7: Green; LED_0603_1608Metric; MPN LTST-C190GKT
Q1: 2N7002H-7; SOT-23; MPN 2N7002H-7
R10, R13: 1k; R_0603_1608Metric; MPN RC0603JR-071KL
R11: 1k; R_Array_Convex_4x0603; MPN YC164-JR-071KL

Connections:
FPGA_CDONE: Q1.1 (G); also elsewhere on the board
GND: D3.1 (K), D4.1 (K), D5.1 (K), D6.1 (K), D7.1 (K), Q1.2 (S); also elsewhere on the board
LED_D0: R11.5; also elsewhere on the board
LED_D1: R11.6; also elsewhere on the board
LED_D2: R11.7; also elsewhere on the board
LED_D3: R11.8; also elsewhere on the board
unnamed: D2.1 (K), Q1.3 (D)
unnamed: D2.2 (A), R10.2
unnamed: D3.2 (A), R11.4
unnamed: D4.2 (A), R11.3
unnamed: D5.2 (A), R11.2
unnamed: D6.2 (A), R11.1
unnamed: D7.2 (A), R13.2
P3V3: R10.1, R13.1; also elsewhere on the board

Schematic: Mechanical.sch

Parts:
FID1, FID2: Fiducial; Fiducial_1mm_Mask2mm
SYM1: Nelgau-Logo; Nelgau-Logo_5.2x1.7mm_SilkScreen



Board: 4 copper layers, 59.2 x 49.2 mm, 126 parts (70 on the bottom side), 193 nets.

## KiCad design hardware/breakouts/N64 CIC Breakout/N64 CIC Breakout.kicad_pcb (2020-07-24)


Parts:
C1: 2u2; C_0805_2012Metric
C2: 100n; C_0805_2012Metric
J1: Conn_02x04_Counter_Clockwise; PinHeader_2x04_P2.54mm_Horizontal
U1: CIC-NUS-6102A; DIP-16_W7.62mm_Socket

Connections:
+3V3: C1.1, C2.1, J1.8, U1.1 (VCC), U1.16 (VCC)
/CIC_DATA1: J1.7, U1.15 (DATA1)
/CIC_DATA2: J1.6, U1.14 (DATA2)
/COLD_RESET#: J1.1, U1.9 (~RESET)
/S_CLK: J1.2, U1.11 (CLK)
GND: C1.2, C2.2, J1.3, J1.4, J1.5, U1.6 (GND), U1.7 (GND), U1.8 (GND), U1.13 (GND)


Board: 2 copper layers, 12.7 x 31.8 mm, 4 parts (0 on the bottom side), 6 nets.

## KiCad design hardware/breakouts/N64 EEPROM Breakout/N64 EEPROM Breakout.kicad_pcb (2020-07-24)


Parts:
C1: 2u2; C_0805_2012Metric
C2: 100n; C_0805_2012Metric
J1: Conn_02x04_Counter_Clockwise; PinHeader_2x04_P2.54mm_Horizontal
U1: BU9850; DIP-8_W7.62mm_Socket

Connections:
+3V3: C1.1, C2.1, J1.8, U1.8 (VCC)
/COLD_RESET#: J1.6, U1.6 (~RESET)
/S_CLK: J1.3, U1.3 (CLK)
/S_DAT: J1.5, U1.5 (DATA)
GND: C1.2, C2.2, J1.1, J1.4, U1.1 (GND), U1.4 (GND)


Board: 2 copper layers, 12.7 x 21.6 mm, 4 parts (0 on the bottom side), 5 nets.

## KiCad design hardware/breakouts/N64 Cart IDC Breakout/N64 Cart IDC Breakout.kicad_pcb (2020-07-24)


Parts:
J1: N64_Cartridge_CardEdge
J2: Conn_02x20_Odd_Even; IDC-Header_2x20_P2.54mm_Vertical
J3: Conn_02x20_Odd_Even; PinSocket_2x20_P2.54mm_Horizontal
J4: Conn_02x11_Odd_Even; PinSocket_2x11_P2.54mm_Horizontal
J5, J6, J7: Conn_02x04_Counter_Clockwise; PinSocket_2x04_P2.54mm_Horizontal

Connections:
+3V3: J1.9 (VCC), J1.17 (VCC), J1.34 (VCC), J1.42 (VCC), J2.13, J2.15, J2.17, J3.13, J3.15, J3.17, J4.11, J5.8, J6.8, J7.8
/AD0: J1.28 (AD0), J2.39, J3.39, J4.21
/AD1: J1.29 (AD1), J2.37, J3.37, J4.19
/AD2: J1.30 (AD2), J2.35, J3.35, J4.17
/AD3: J1.32 (AD3), J2.33, J3.33, J4.15
/AD4: J1.36 (AD4), J2.25, J3.25, J4.22
/AD5: J1.37 (AD5), J2.23, J3.23, J4.20
/AD6: J1.40 (AD6), J2.21, J3.21, J4.18
/AD7: J1.41 (AD7), J2.19, J3.19, J4.16
/AD8: J1.16 (AD8), J2.20, J3.20, J4.8
/AD9: J1.15 (AD9), J2.22, J3.22, J4.6
/AD10: J1.12 (AD10), J2.24, J3.24, J4.4
/AD11: J1.11 (AD11), J2.26, J3.26, J4.2
/AD12: J1.7 (AD12), J2.34, J3.34, J4.7
/AD13: J1.5 (AD13), J2.36, J3.36, J4.5
/AD14: J1.4 (AD14), J2.38, J3.38, J4.3
/AD15: J1.3 (AD15), J2.40, J3.40, J4.1
/ALE_H: J1.35 (ALE_H), J2.27, J3.27, J4.9
/ALE_L: J1.33 (ALE_L), J2.31, J3.31, J4.13
/CIC_DATA1: J1.18 (CIC_DATA1_15), J2.10, J3.10, J5.7
/CIC_DATA2: J1.43 (CIC_DATA2_14), J2.9, J3.9, J5.6
/COLD_RESET#: J1.20 (~COLD_RESET), J2.5, J3.5, J5.1, J7.6
/MITM_CLK: J2.2, J3.2, J6.2
/MITM_DATA1: J2.4, J3.4, J6.7
/MITM_DATA2: J2.3, J3.3, J6.6
/MITM_RESET#: J2.1, J3.1, J6.1
/OS_EVENT#: J1.45 (~OS_EVENT), J2.6, J3.6
/READ#: J1.10 (~READ), J2.28, J3.28, J4.10
/S_CLK: J1.19 (S_CLK), J2.8, J3.8, J5.2, J7.3
/S_DAT: J1.21 (S_DAT), J2.7, J3.7, J7.5
/WRITE#: J1.8 (~WRITE), J2.32, J3.32, J4.14
GND: J1.1 (GND), J1.2 (GND), J1.6 (GND), J1.22 (GND), J1.23 (GND), J1.25 (GND), J1.26 (GND), J1.27 (GND), J1.31 (GND), J1.47 (GND), J1.48 (GND), J1.50 (GND), J2.12, J2.14, J2.16, J2.18, J2.30, J3.12, J3.14, J3.16, J3.18, J3.30, J4.12, J5.3, J5.4, J5.5, J6.3, J6.4, J6.5, J7.1, J7.4

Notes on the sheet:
FPGA
IDC
CIC CART
CIC MITM
MASK ROM
EEPROM
CART BUS



Board: 2 copper layers, 145.0 x 36.8 mm, 9 parts (6 on the bottom side), 32 nets.

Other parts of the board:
M1, M2: MountingHole_3.2mm_M3_Pad

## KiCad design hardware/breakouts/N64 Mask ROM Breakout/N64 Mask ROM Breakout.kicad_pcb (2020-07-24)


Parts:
C1: 2u2; C_0805_2012Metric
C2, C3, C4: 100n; C_0805_2012Metric
J1: Conn_02x11_Odd_Even; PinHeader_2x11_P2.54mm_Horizontal
U1: MX23L6402-35A; DIP-28_W15.24mm_Socket

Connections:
+3V3: C1.1, C2.1, C3.1, C4.1, J1.11, U1.5 (VCC), U1.19 (VCC), U1.22 (VCC)
/AD0: J1.21, U1.1 (AD0)
/AD1: J1.19, U1.2 (AD1)
/AD2: J1.17, U1.3 (AD2)
/AD3: J1.15, U1.4 (AD3)
/AD4: J1.22, U1.11 (AD4)
/AD5: J1.20, U1.12 (AD5)
/AD6: J1.18, U1.13 (AD6)
/AD7: J1.16, U1.14 (AD7)
/AD8: J1.8, U1.15 (AD8)
/AD9: J1.6, U1.16 (AD9)
/AD10: J1.4, U1.17 (AD10)
/AD11: J1.2, U1.18 (AD11)
/AD12: J1.7, U1.25 (AD12)
/AD13: J1.5, U1.26 (AD13)
/AD14: J1.3, U1.27 (AD14)
/AD15: J1.1, U1.28 (AD15)
/ALE_H: J1.9, U1.9 (ALE_H)
/ALE_L: J1.13, U1.6 (ALE_L)
/READ#: J1.10, U1.7 (~READ), U1.20 (~READ)
/WRITE#: J1.14
GND: C1.2, C2.2, C3.2, C4.2, J1.12, U1.8 (GND), U1.10 (GND), U1.23 (GND), U1.24 (GND)


Board: 2 copper layers, 30.5 x 49.3 mm, 6 parts (0 on the bottom side), 21 nets.

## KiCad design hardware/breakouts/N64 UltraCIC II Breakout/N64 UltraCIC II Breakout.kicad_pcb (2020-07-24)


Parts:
C1: 2u2; C_0805_2012Metric
C2: 100n; C_0805_2012Metric
J1: Conn_02x04_Counter_Clockwise; PinHeader_2x04_P2.54mm_Horizontal
U1: ATtiny45-20SU; SOIJ-8_5.3x5.3mm_P1.27mm

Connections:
+3V3: C1.1, C2.1, J1.8, U1.8 (VCC)
/CIC_DATA1: J1.7, U1.7 (PB2)
/CIC_DATA2: J1.6, U1.6 (PB1)
/COLD_RESET#: J1.1, U1.1 (~RESET~/PB5)
/S_CLK: J1.2, U1.2 (XTAL1/PB3)
GND: C1.2, C2.2, J1.3, J1.4, J1.5, U1.4 (GND), U1.5 (AREF/PB0)


Board: 2 copper layers, 12.7 x 16.5 mm, 4 parts (0 on the bottom side), 6 nets.

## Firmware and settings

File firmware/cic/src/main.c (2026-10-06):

// **** ADDED BY HICART ****

#include <riscv.h>



// *************************

/**************************************************************
 * Generic CIC implementation for N64                         *
 * ---------------------------------------------------------- *
 * This should run on every MCU which is fast enough to       *
 * handle the IO operations.                                  *
 * You just have to implement the low level gpio functions:   *
 *     - ReadBit() and                                        *
 *     - WriteBit().                                          *
 *                                                            *
 * Hardware connections                                       *
 * Data Clock Input (DCLK): CIC Pin 14                        *
 * Data Line, Bidir (DIO):  CIC Pin 15                        *
 *                                                            *
 **************************************************************/

#define REGION_NTSC (0)
#define REGION_PAL  (1)

#define GET_REGION() (REGION_NTSC)

/* SEEDs */

// 6102/7101
#define CIC6102_SEED 0x3F

// 6101
#define CIC6101_SEED 0x3F

// 6103/7103
#define CIC6103_SEED 0x78

// 6105/7105
#define CIC6105_SEED 0x91

// 6106/7106
#define CIC6106_SEED 0x85

// 7102
#define CIC7102_SEED 0x3F

/* CHECKSUMs */

// 6102/7101
#define CIC6102_CHECKSUM 0xa, 0x5, 0x3, 0x6, 0xc, 0x0, 0xf, 0x1, 0xd, 0x8, 0x5, 0x9

// 6101
#define CIC6101_CHECKSUM 0x4, 0x5, 0xC, 0xC, 0x7, 0x3, 0xE, 0xE, 0x3, 0x1, 0x7, 0xA

// 6103/7103
#define CIC6103_CHECKSUM 0x5, 0x8, 0x6, 0xf, 0xd, 0x4, 0x7, 0x0, 0x9, 0x8, 0x6, 0x7

// 6105/7105
#define CIC6105_CHECKSUM 0x8, 0x6, 0x1, 0x8, 0xA, 0x4, 0x5, 0xB, 0xC, 0x2, 0xD, 0x3

// 6106/7106
#define CIC6106_CHECKSUM 0x2, 0xB, 0xB, 0xA, 0xD, 0x4, 0xE, 0x6, 0xE, 0xB, 0x7, 0x4

// 7102
#define CIC7102_CHECKSUM 0x4, 0x4, 0x1, 0x6, 0x0, 0xE, 0xC, 0x5, 0xD, 0x9, 0xA, 0xF

void EncodeRound(unsigned char index);
void CicRound(unsigned char *);
void Cic6105Algo(void);

/* Select SEED and CHECKSUM here */
const unsigned char _CicSeed = CIC6102_SEED;

const unsigned char _CicChecksum[] = {
    CIC6102_CHECKSUM
};


/* NTSC initial RAM */
const unsigned char _CicRamInitNtsc[] = {
    0xE, 0x0, 0x9, 0xA, 0x1, 0x8, 0x5, 0xA, 0x1, 0x3, 0xE, 0x1, 0x0, 0xD, 0xE, 0xC,
    0x0, 0xB, 0x1, 0x4, 0xF, 0x8, 0xB, 0x5, 0x7, 0xC, 0xD, 0x6, 0x1, 0xE, 0x9, 0x8
};

/* PAL initial RAM */
const unsigned char _CicRamInitPal[] = {
    0xE, 0x0, 0x4, 0xF, 0x5, 0x1, 0x2, 0x1, 0x7, 0x1, 0x9, 0x8, 0x5, 0x7, 0x5, 0xA,
    0x0, 0xB, 0x1, 0x2, 0x3, 0xF, 0x8, 0x2, 0x7, 0x1, 0x9, 0x8, 0x1, 0x1, 0x5, 0xC
};

/* Memory for the CIC algorithm */
unsigned char _CicMem[32];

/* Memory for the 6105 algorithm */
unsigned char _6105Mem[32];

/* YOU HAVE TO IMPLEMENT THE LOW LEVEL GPIO FUNCTIONS ReadBit() and WriteBit() */

/* Read a bit synchronized by DCLK */
unsigned char ReadBit(void)
{
    volatile unsigned long *gpio_input  = (void *)0x00006001;

    unsigned char res;

    // wait for DCLK to go low
    while (*gpio_input & 0x1) { }

    // Read the data bit
    res = !!(*gpio_input & 0x2);

    // wait for DCLK to go high
    while (!(*gpio_input & 0x1)) { }

    return res;
}

/* Write a bit synchronized by DCLK */
void WriteBit(unsigned char b)
{
    volatile unsigned long *gpio_mode   = (void *)0x00006000;
    volatile unsigned long *gpio_input  = (void *)0x00006001;
    volatile unsigned long *gpio_output = (void *)0x00006002;

    // wait for DCLK to go low
    while (*gpio_input & 0x1) { }

    if (b == 0)
    {
        // drive the output low
        *gpio_output = 0x0;
        *gpio_mode = 0x4;
    }

    // wait for DCLK to go high
    while (!(*gpio_input & 0x1)) { }

    //
    // NOTE: It may be necessary to add a delay here to meet the PIF's
    // setup and hold requirements. Not sure yet...
    //

    // disable the output
    *gpio_mode = 0x0;
}

/* Writes the lowes 4 bits of the byte */
void WriteNibble(unsigned char n)
{
    WriteBit(n & 0x08);
    WriteBit(n & 0x04);
    WriteBit(n & 0x02);
    WriteBit(n & 0x01);
}

// Write RAM nibbles until index hits a 16 Byte border
void WriteRamNibbles(unsigned char index)
{
    do
    {
        WriteNibble(_CicMem[index]);
        index++;
    } while ((index & 0x0f) != 0);
}

/* Reads 4 bits and returns them in the lowes 4 bits of a byte */
unsigned char ReadNibble(void)
{
    unsigned char res = 0;
    unsigned char i;
    for (i = 0; i < 4; i++)
    {
        res <<= 1;
        res |= ReadBit();
    }
    return res;
}

/* Encrypt and output the seed */
void WriteSeed(void)
{
    _CicMem[0x0a] = 0xb;
    _CicMem[0x0b] = 0x5;
    _CicMem[0x0c] = _CicSeed >> 4;
    _CicMem[0x0d] = _CicSeed;
    _CicMem[0x0e] = _CicSeed >> 4;
    _CicMem[0x0f] = _CicSeed;

    EncodeRound(0x0a);
    EncodeRound(0x0a);
    WriteRamNibbles(0x0a);
}

/* Encrypt and output the checksum */
void WriteChecksum(void)
{
    unsigned char i;
    for (i = 0; i < 12; i++)
        _CicMem[i + 4] = _CicChecksum[i];

    // wait for DCLK to go low
    // (doesn't seem to be necessary)

    // "encrytion" key
    // initial value doesn't matter
    _CicMem[0x00] = 0x9;
    _CicMem[0x01] = 0x8;
    _CicMem[0x02] = 0xc;
    _CicMem[0x03] = 0xa;

    EncodeRound(0x00);
    EncodeRound(0x00);
    EncodeRound(0x00);
    EncodeRound(0x00);

    // signal that we are done to the pif
    // (test with WriteBit(1) also worked)
    WriteBit(0);

    // Write 16 nibbles
    WriteRamNibbles(0);
}

/* seed and checksum encryption algorithm */
void EncodeRound(unsigned char index)
{
    unsigned char a;

    a = _CicMem[index];
    index++;

    do
    {
        a = (a + 1) & 0x0f;
        a = (a + _CicMem[index]) & 0x0f;
        _CicMem[index] = a;
        index++;
    } while ((index & 0x0f) != 0);
}

/* Exchange value of a and b */
void Exchange(unsigned char *a, unsigned char *b)
{
    unsigned char tmp;
    tmp = *a;
    *a = *b;
    *b = tmp;
}

// translated from PIC asm code (thx to Mike Ryan for the PIC implementation)
// this implementation saves program memory in LM8

/* CIC compare mode memory alternation algorithm */
void CicRound(unsigned char * m)
{
    unsigned char a;
    unsigned char b, x;

    x = m[15];
    a = x;

    do
    {
        b = 1;
        a += m[b] + 1;
        m[b] = a;
        b++;
        a += m[b] + 1;
        Exchange(&a, &m[b]);
        m[b] = ~m[b];
        b++;
        a &= 0xf;
        a += (m[b] & 0xf) + 1;
        if (a < 16)
        {
            Exchange(&a, &m[b]);
            b++;
        }
        a += m[b];
        m[b] = a;
        b++;
        a += m[b];
        Exchange(&a, &m[b]);
        b++;
        a &= 0xf;
        a += 8;
        if (a < 16)
            a += m[b];
        Exchange(&a, &m[b]);
        b++;
        do
        {
            a += m[b] + 1;
            m[b] = a;
            b++;
            b &= 0xf;
        } while (b != 0);
        a = x + 0xf;
        x = a & 0xf;
    } while (x != 15);
}

// Big Thx to Mike Ryan, John McMaster, marshallh for publishing their work

/* CIC 6105 algorithm */
void Cic6105Algo(void)
{
    unsigned char A = 5;
    unsigned char carry = 1;
    unsigned char i;
    for (i = 0; i < 30; ++i)
    {
        if (!(_6105Mem[i] & 1))
            A += 8;
        if (!(A & 2))
            A += 4;
        A = (A + _6105Mem[i]) & 0xf;
        _6105Mem[i] = A;
        if (!carry)
            A += 7;
        A = (A + _6105Mem[i]) & 0xF;
        A = A + _6105Mem[i] + carry;
        if (A >= 0x10)
        {
            carry = 1;
            A -= 0x10;
        }
        else
        {
            carry = 0;
        }
        A = (~A) & 0xf;
        _6105Mem[i] = A;
    }
}

/* Wait for reset */
void Die(void)
{
    // never return
    while (1)
    { }
}

/* CIC compare mode */
void CompareMode(unsigned char isPal)
{
    unsigned char ramPtr;
    // don't care about the low ram as we don't check this
//  CicRound(&_CicMem[0x00]);
//  CicRound(&_CicMem[0x00]);
//  CicRound(&_CicMem[0x00]);

    // only need to calculate the high ram
    CicRound(&_CicMem[0x10]);
    CicRound(&_CicMem[0x10]);
    CicRound(&_CicMem[0x10]);

    // 0x17 determines the start index (but never 0)
    ramPtr = _CicMem[0x17] & 0xf;
    if (ramPtr == 0)
        ramPtr = 1;
    ramPtr |= 0x10;

    do
    {
        // read the bit from PIF (don't care about the value)
        ReadBit();

        // send out the lowest bit of the currently indexed ram
        WriteBit(_CicMem[ramPtr] & 0x01);

        // PAL or NTSC?
        if (!isPal)
        {
            // NTSC
            ramPtr++;
        }
        else
        {
            // PAL
            ramPtr--;
        }

        // repeat until the end is reached
    } while (ramPtr & 0xf);
}

/* CIC 6105 mode */
void Cic6105Mode(void)
{
    unsigned char ramPtr;

    // write 0xa 0xa
    WriteNibble(0xa);
    WriteNibble(0xa);

    // receive 30 nibbles
    for (ramPtr = 0; ramPtr < 30; ramPtr++)
    {
        _6105Mem[ramPtr] = ReadNibble();
    }

    // execute the algorithm
    Cic6105Algo();

    // send bit 0
    WriteBit(0);

    // send 30 nibbles
    for (ramPtr = 0; ramPtr < 30; ramPtr++)
    {
        WriteNibble(_6105Mem[ramPtr]);
    }
}

/* Load initial ram depending on region */
void InitRam(unsigned char isPal)
{
    unsigned char i;

    if (!isPal)
    {
        for (i = 0; i < 32; i++)
            _CicMem[i] = _CicRamInitNtsc[i];
    }
    else
    {
        for (i = 0; i < 32; i++)
            _CicMem[i] = _CicRamInitPal[i];
    }
}

void ClearRam(void)
{
    unsigned char i;

    for (i = 0; i < 32; i++) {
        _CicMem[i] = 0;
        _6105Mem[i] = 0;
    }
}

int main(void)
{
    // **** ADDED BY HICART ****

    // Enable IRQ0 and machine interrupts
    irq_setmask(0x1);
    irq_setie(0x1);

    // *************************


    unsigned char isPal;

    // ClearRam();

    // read the region setting
    isPal = GET_REGION();

    // send out the corresponding id
    unsigned char hello = 0x1;
    if (isPal)
        hello |= 0x4;
    WriteNibble(hello);

    // encode and send the seed
    WriteSeed();

    // encode and send the checksum
    WriteChecksum();

    // init the ram corresponding to the region
    InitRam(isPal);

    // read the initial values from the PIF
    _CicMem[0x01] = ReadNibble();
    _CicMem[0x11] = ReadNibble();

    while(1)
    {
        // read mode (2 bit)
        unsigned char cmd = 0;
        cmd |= (ReadBit() << 1);
        cmd |= ReadBit();
        switch (cmd)
        {
        case 0:
            // 00 (compare)
            CompareMode(isPal);
            break;

        case 2:
            // 10 (6105)
            Cic6105Mode();
            break;

        case 3:
            // 11 (reset)
            WriteBit(0);
            break;

        case 1:
            // 01 (die)
        default:
            Die();
        }
    }
}

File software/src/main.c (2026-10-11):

#include <stdio.h>
#include <errno.h>
#include <libdragon.h>
#include "cmd.h"
#include "soak.h"
#include "regs.h"
#include "sdhi.h"

int main(void)
{
    console_init();

    debug_init_usblog();
    console_set_debug(true);

    sdhi_init();

    // run_soak();

    FILE *f = fopen("sdhi:/example.txt", "r");
    if (!f) {
        printf("open failed %s\n", strerror(errno));
    } else {
        char buf[128] = {0};
        fread(buf, 1, sizeof(buf) - 1, f);
        printf("%s\n", buf);
        fclose(f);
    }
}

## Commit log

2020-06-09 Add memory ICs and partial build out of power managment
    [fpga-ice40.kicad_pcb, fpga-ice40.sch]
2020-06-10 Use a combined SOIC-8/16W layout for flash ICs
    [fpga-ice40.kicad_pcb, fpga-ice40.sch]
2020-06-14 Begin pin assignments from FPGA to N64 bus and SDRAM
    [fpga-ice40.kicad_pcb, fpga-ice40.sch]
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2020-06-21 Routing FPGA to SPI flash memory and USB interface
    [fpga-ice40.kicad_pcb, fpga-ice40.sch]
2020-06-23 Oscillator, LEDs implemented, with all traces routed roughly
    [fpga-ice40.kicad_pcb, fpga-ice40.sch]
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2020-06-23 Reroute N64 AD cart net away from clock oscillator output net
    [fpga-ice40.kicad_pcb, fpga-ice40.sch]
2020-06-23 Completed first pass routing with DRC checks passing
    [fpga-ice40.kicad_pcb, fpga-ice40.sch]
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2020-06-23 Clean up overhanging silkscreen on main 2x20 header
    [fpga-ice40.kicad_pcb, fpga-ice40.sch]
2020-06-23 N64 cart bus track glossing and front silkscreen cleanup
    [fpga-ice40.kicad_pcb, fpga-ice40.sch]
2020-06-23 Use FTSH footprint with mating geometry and cleanup silkscreen
    [fpga-ice40.kicad_pcb, fpga-ice40.sch]
2020-06-24 First pass at adding bulk traces and copper pours for power
    [fpga-ice40.kicad_pcb]
2020-06-24 Small cleanups before starting the final check list
    [fpga-ice40.kicad_pcb]
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2020-06-30 Flash programming header can hold FPGA in configuration reset
    [FPGA_Config.sch, Interface_N64.sch, Interface_Prog.sch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]
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2020-06-30 Repair routing after adding new behavior to flash programming header
    [fpga-ice40.kicad_pcb]
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2020-06-30 Simplify FPGA reset logic layout with resistor array
    [FPGA_Config.sch, fpga-ice40.kicad_pcb]
2020-06-30 Cleanup CDONE led indicator and add copyright notice
    [fpga-ice40.kicad_pcb]
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2020-07-01 Completed verification of all pins for all symbols
    [FPGA_Config.sch, FPGA_IO.sch, Interface_N64.sch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]
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2020-07-05 Fix mechanical issue by moving USB connector to top of board
    [Display.sch, FPGA_IO.sch, Interface_N64.sch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]
2020-07-06 Continuing routing after replacement
    [FPGA_IO.sch, fpga-ice40.kicad_pcb]
2020-07-06 Routed N64, DRAM, FIFO, and SD card interfaces
    [FPGA_IO.sch, Interface_N64.sch, Interface_USB.sch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]
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2020-07-07 Fix two misrouted power traces in USB section
    [Interface_USB.sch, fpga-ice40.kicad_pcb]
2020-07-07 Fix misrouted power traces
    [fpga-ice40.kicad_pcb]
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2020-07-07 Add copper zones to high current USB power traces
    [fpga-ice40.kicad_pcb]
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2020-07-07 Add 'no connect' symbol to unused FPGA I/O pins
    [FPGA_IO.sch, fpga-ice40.kicad_pcb]
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2020-07-08 Fix a few via/silkscreen collisions
    [fpga-ice40.kicad_pcb]
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2020-07-08 Fix DRC violations and unconnected nets
    [fpga-ice40.kicad_pcb]
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2020-07-14 Swtich USB interface to P3V3 and add 12MHz oscillator
    [Interface_USB.sch, fpga-ice40.kicad_pcb]
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2020-07-22 Swap in Nelgau-Logo symbol footprint
    [Mechanical.sch, fpga-ice40.kicad_pcb]
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2020-08-03 Ensure solder mask covers copper zones near BGA pads
    [cart-ecp5.kicad_pcb]
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2020-08-15 Generate production gerbers for first revision of fpga-ice40
    [fpga-ice40-B_Cu.gbr, fpga-ice40-B_Mask.gbr, fpga-ice40-B_Paste.gbr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]
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2020-08-24 Add power muxing and regulators for P3V3, P2V5, and P1V1 rails
    [FPGA-IO.sch, FPGA-Power.sch, Interface-N64.sch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]
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2020-08-24 Fix fpga-ice40 schematic after Kicad library update
    [Interface_USB.sch]
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2020-08-25 Replace FT2232HL with FT2232HQ for QFN-64 package
    [Interface-USB.sch]
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2020-08-25 Fixes for footprint assignment
    [FPGA-IO.sch, Power.sch]
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2020-08-26 Refine placement to make room for power management
    [FPGA-IO.sch, FPGA-Power.sch, Interface-N64.sch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]
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2020-08-30 Fixes to length matching script, now configured for hyperram
    [FPGA-IO.sch, Memory.sch, cart-ecp5.kicad_pcb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]
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2020-09-05 Add TPS2121 power mux to schematic and assign footprints
    [Power.sch]
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2020-09-05 Add a switching supply for a 1V8 rail
    [Power.sch, cart-ecp5.kicad_pcb]
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2020-09-06 Place bypass caps along right side of FPGA and optimize power island
    [cart-ecp5.kicad_pcb]
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2020-09-07 Update config flash to WSON package, add HyperRAM decoupling
    [FPGA-IO.sch, Memory.sch, cart-ecp5.kicad_pcb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]
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2020-09-08 Route configuration flash and JTAG, develop power island design
    [cart-ecp5.kicad_pcb]
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2020-09-08 Reverse USB input protection polarity
    [Interface-USB.sch, cart-ecp5.kicad_pcb]
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2020-09-09 Fanout MicroSD and N64 interfaces on the top layer
    [FPGA-IO.sch, Power.sch, cart-ecp5.kicad_pcb]
2020-09-09 Assign FPGA IO for N64_CIC_DATA[12] and add series termination
    [FPGA-IO.sch, Interface-N64.sch, cart-ecp5.kicad_pcb]
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2020-09-09 Isolate USB P1V8, VPHY, and VPLL rails to local sheet
    [Interface-USB.sch, cart-ecp5.kicad_pcb]
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2020-09-09 Connect N64 cartridge edge connector to termination resistors
    [cart-ecp5.kicad_pcb]
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2020-09-10 More switcher zone fixes
    [cart-ecp5.kicad_pcb]
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2020-09-10 Move JTAG connector to make space for logo
    [cart-ecp5.kicad_pcb]
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2020-09-10 Tighten up switcher placement to gauge available space
    [cart-ecp5.kicad_pcb]
2020-09-11 Adjust trace widths and spacings for impedance control
    [Memory.sch, cart-ecp5.kicad_pcb]
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2020-09-11 Adjust the P1V8 power plane to insect the switcher output
    [cart-ecp5.kicad_pcb]
2020-09-11 Add more clearance to FT2232H interface to study length matching
    [cart-ecp5.kicad_pcb]
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2020-09-11 Finish adding copper zones to the power mux
    [cart-ecp5.kicad_pcb]
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2020-09-13 Assign FPGA IO for debugging LEDs and route signals
    [FPGA-IO.sch, cart-ecp5.kicad_pcb]
2020-09-13 Move MicroSD connector to top edge to make room for passthrough connectors
    [cart-ecp5.kicad_pcb]
2020-09-14 Prepare to move FPGA to the left for passthrough
    [cart-ecp5.kicad_pcb]
2020-09-14 Study placement of passthrough and optional PMOD connector
    [cart-ecp5.kicad_pcb]
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2020-09-16 Add notes on FT245 synchronous FIFO clock signal
    [FPGA-IO.sch, Interface-USB.sch, cart-ecp5.kicad_pcb]
2020-09-24 Move low-value FPGA decoupling caps to bottom layer
    [FPGA-Power.sch, cart-ecp5.kicad_pcb]
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2020-09-25 Assign FPGA IO for main clock, adjust placement of core switcher
    [FPGA-IO.sch, FPGA-Power.sch, cart-ecp5.kicad_pcb]
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2020-10-22 Assign the USB interface synchronous clock output (AC5) to an FPGA primary clock input
    [FPGA-IO.sch, cart-ecp5.kicad_pcb]
2020-11-29 Remove front/back ground pours and create local zones for shield connections
    [cart-ecp5.kicad_pcb]
2020-11-29 Complete routing power rails and clean up traces
    [cart-ecp5.kicad_pcb]
2020-11-29 Incrase clearance between GPIO LEDs and shield connection
    [cart-ecp5.kicad_pcb]
2020-11-29 Substitute QE=1 config flash to keep boot time as short as possible
    [FPGA-IO.sch, cart-ecp5.kicad_pcb]
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2020-11-30 Fix the configuration flash's decoupling capacitor
    [FPGA-IO.sch]
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2020-11-30 Add testpoints for clock oscillator outputs
    [FPGA-IO.sch, Interface-USB.sch]
2020-11-30 Layout testpoints for power rails and clock oscillators
    [FPGA-IO.sch, Interface-USB.sch, Power.sch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]
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2021-01-03 Use 0402 package for all 4u7 bypass capacitors
    [Interface-USB.sch, cart-ecp5.kicad_pcb]
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2021-01-06 Clarify pull-up design for configuration flash and FPGA reset signal
    [FPGA-IO.sch, cart-ecp5.kicad_pcb]
2021-01-06 Add header for injecting 3V3 rail without populating USB_3V3 regulator and power mux
    [Power.sch, cart-ecp5.kicad_pcb]
2021-01-06 Check all resistor values for power management and assign MPN for caps and resistors
    [Display.sch, FPGA-IO.sch, FPGA-Power.sch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]
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2021-01-24 Assign MPN for all other components except oscillators
    [FPGA-IO.sch, Interface-N64.sch, Interface-USB.sch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]
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2021-01-26 Fix FPGA_CDONE net namespacing and add DNP pull-up resistor
    [FPGA-IO.sch, cart-ecp5.kicad_pcb]
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2021-01-30 Replace 2.5x2.0mm oscillators with SiT2001B SOT23-5 oscillators
    [FPGA-IO.sch, Interface-USB.sch, cart-ecp5.kicad_pcb]
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2021-01-30 Set solder paste absolute clearance to 0
    [cart-ecp5.kicad_pcb]
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2021-02-03 Fix for ATtiny45 MPN
    [Interface-N64.sch]
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2022-10-06 Fix failing test in hicart.n64.pi
    The initiator's wishbone bus uses the stall feature. To be connectable, the
    DUT's decoder needs to support that feature as well.
    [pi.py]
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2022-10-12 Fix for when {build,traces} directories exist
2022-10-12 Solved the iverilog combinatorial loop
    Simulators, such as Icarus Verilog and Verilator, require a diffferent
    style of combinatorial loop. Adding the `regular_comb=False` generates
    simulation-compatible combinatoral logic. This is required by LiteDRAM
    as well, suggesting the issue plagues more than just LiteSDCard.
    Enjoy-Digital also recommended this fix for combinatorial simulation
    loop in this Twitter thread:
    https://twitter.com/yannsionneau/status/1462409247807967234
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2023-09-12 gate: Pin instances can no longer be cast to value directly
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2023-09-15 soft: Update libdragon to use upstream unstable branch
    [main.c]
2023-09-16 soft: Disable isviewer and usblog, gateware is incompatible?
    [main.c]
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2023-09-25 gate: Fix incorrect granularity of the burst and wishbone buses
    [cart.py, pi.py]
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2023-09-25 gate: Skip cocotb tests until they can be rewritten to use lib.wiring
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2023-09-29 gate: Replace old pi bridge
    [cart.py, pi.py]
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2023-10-06 gate: Wishbone decoder now has the correct signature
    [cart.py, cic.py]
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2023-10-20 gate: Correct signal names in CIC component
    [cic.py]
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2024-02-29 software: Pin libdragon to avoid recent YUV bug
2024-02-29 software: Avoid deprecated initialization function
    [main.c]
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2024-05-02 hardware: Fix swapped USB nets on schematic
    [Interface-USB.kicad_sch, cart-ecp5.kicad_pcb]
2024-05-03 hardware: Adjust copper to hole clearance for BGA breakout
    [cart-ecp5.kicad_pcb]
2024-05-04 hardware: Fix mounting hole clearances
    [cart-ecp5.kicad_pcb]
2024-05-05 hardware: Fix USB connector NPTH clearance
    [cart-ecp5.kicad_pcb]
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2024-05-09 hardware: Fix silkscreen overlapping board edge
    [cart-ecp5.kicad_pcb]
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2024-05-20 hardware: Solve clearances for USB serial EEPROM
    [cart-ecp5.kicad_pcb]
2024-05-21 hardware: Solve clearances for P2V5 regulator
    [cart-ecp5.kicad_pcb]
2024-05-22 hardware: Solve clearances for USB_3V3 regulator
    [cart-ecp5.kicad_pcb]
2024-05-23 hardware: Solve clearances for P1V1 regulator
    [cart-ecp5.kicad_pcb]
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2026-09-27 gateware: No longer depend on amaranth-boards
    [cart.py]
2026-09-29 gateware: Decoder match failure is a bus error
    [seqbus.py]
2026-09-30 gateware: Fix sampling order in wishbone driver
    [wishbone.py]
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2026-10-01 gateware: MCU ping pong working, endianness issue
    [main.c]
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2026-10-06 gateware: Don't use interrupt to reset CIC
    [cic.py, main.c]
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

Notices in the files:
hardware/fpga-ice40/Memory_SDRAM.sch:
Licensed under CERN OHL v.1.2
